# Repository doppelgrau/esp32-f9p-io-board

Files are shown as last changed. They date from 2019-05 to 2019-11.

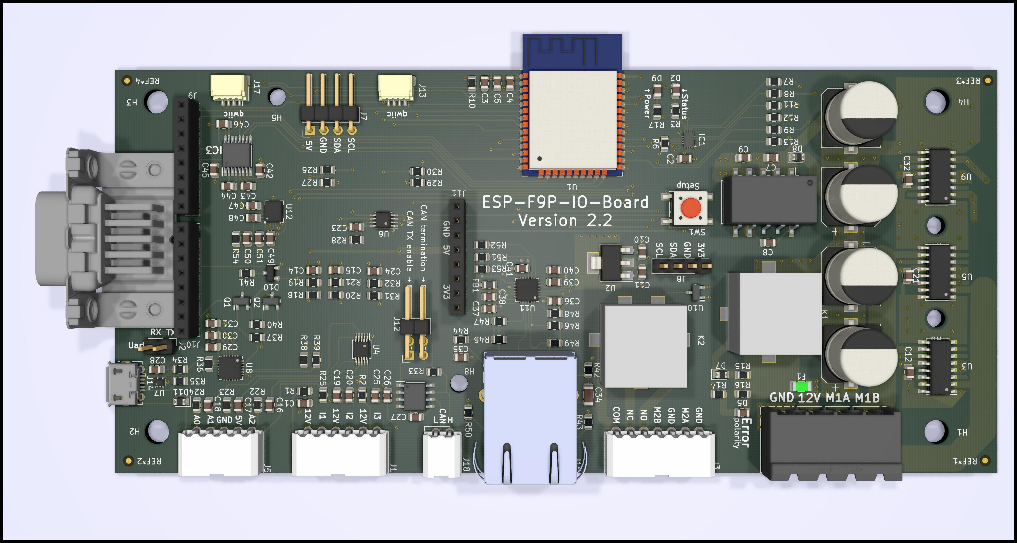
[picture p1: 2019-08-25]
pcb/mainPCB.jpeg

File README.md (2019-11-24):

# ESP32 F9P IO board

This PCB is a versatile IO plattform that provides computing power (ESP32) and IO interfaces to build GPS/RTK applications.

## Hardware Overview

- Power supply: 
    - Input 9V-28V (labeld 12V on the board), external connection on J4. 
    - Protected against wrong polarity (Diode D7 parallel to the relay K1)
    - Reduced inrush current (resistors R15/16 in serie with the starting diode D7 before the relay K1 closes and shortens the path).
    - V78E05-1000 (step down converter) PS1 generates 5V
    - AZ1117-3.3 LDO U2 generates 3V from the 5V supply.
    - 12A (slow) fuse soldered on the board. Recommended to use a 10A external fuse.
- ESP32-WROOM-32 U1 for computing-power, wifi, Bluetooth
- Arduino headers for the simpleRTK2B-F9P (uart 1 of the F9P connected)
- Serial interfaces
    - one uart (IO13/14) on the Arduino headers for the F9P
    - one uart (IO0/2) next to the arduino headers on two pins (J2) for the new simpleRTK2Blight. Since the two pins have a special meaning during boot, pulling TX to GND during startup results in the ESP going into programming mode.
    - one uart (IO15/16) for RS232 on the D-Sub connector J16
    - one uart (IO1/3) on the USB-Uart converter (J14) - Also supports programming with "RTS/DTR"
- I2C (IO32/33)
    - I2C with 3.3V logic level (J8 pin header, J13,17 [qwiic](https://www.sparkfun.com/qwiic) connector)
    - I2C with 5V logic level (J7 pin header)
    - internal used adresses:
        - 0x1C - Magnetometer part of the LSM9DS1 (U12)
        - 0x43 - FXL6408 port extender (IC 1)
        - 0x48 - ADS1115 (U4)
        - 0x6A - Accelerometer part of the LSM9DS1 (U12)
- CAN bus
    - Tranceiver (U2) + ESP32 integrated controler (TX IO5, RX IO35)
    - Termination resistor and sending messages can/must both be enabled with a jumper on J12
    - external connection J18
- Ethernet:
    - internal MAC, connected to LAN8720A on IO17,18,19,21,22,23,25,26,27
        - IO17 Clock
        - IO18 MDIO
        - IO23 MDC
    - PHY-Reset controlled with FXL6408-GPI01
    - ETH-Address of the LAN8720: 0
- IMU: 9 Axis, LSM9DS1 (U12). Magnetometer needs iron correction to be usable.
- Outputs
    - One H-bridge/motordriver with two VNH7070AS (U3/5), (PWM IO4, FXL6408-GPIO6/7 direction). External connected on J4
    - One H-bridge/motordriver with one VNH7070AS (U9), (PWM IO12, FXL6408-GPI04/5 direction), external connected on J3
    - One Relay (K2) controlled on FXL6408-GPI03, external connected on J3
    - One status LED (D2) controlled on FXL6408-GPI02
- Inputs
    - Three 15V tolerant (analog) inputs IO34, SENSOR_VN/36, SENSOR_VP/39, external connected on J1
    - Three 5V tolerant (analog) inputs on the ADS1115, first two cann be used to measure differential. Number four is hardwired to VCC/5V. External connected on J5
    - One Button (e.g. for entering configuration mode), on FXL6408-GPI00
- Connectors:
    - J1 - 6 pin PTSM header. 15V tolerant inputs and 12V for easy cabeling if used as switch
    - J2 - 2 Pin Uart
    - J3 - 7 pin PTSM header. Outputs of second H-bridge, two times ground (for using as two half bridges) and the three pins for the relay (comm, no, nc)
    - J4 - 4 pin CCA header. Power input and output of the first motor driver/h-bridge
    - J5 - 5 pin PTSM header. Three ADS1115 inputs, 5V and GND for easy cabeling (e.g. linear potentiometer)
    - J7 - 4 pin header. I2C 5V logic level + GND and 5V
    - J8 - 4 pin header. I2C 3V3 logic level + GND and 3V3
    - J9, J10, J11 - 8 pin header. Socket for the simpleRTK2B F9P
    - J12 - 2x2 horizontal pin header. Used for jumpers to enable CAN termination and/or CAN TX
    - J13, J17 - qwiic connector. I2C 3V3
    - J14 - micro USB connector. Can power 5V and 3V3 part of the PCB. Electricaly not isolated! Used for programming the ESP32
    - J15 - RJ45 ethernet connector
    - J16 - D-Sub connector (male). RS232
    - J18 - 2 pin PTSM header. CAN bus

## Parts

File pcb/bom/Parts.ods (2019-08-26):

Ref | Qnty | Value | Mouser Partnumber | Mouser Alternative | Digikey | Cmp name | Footprint | Description | Vendor
C1, C3, C4, C2, C8, C12, C19, C21, C27, C26, C28, C30, C29, C32, C35, C39, C41, C36, C38, C45, C44, C46, C43, C42, C51, C49, C48, | 27 | 100n | 603-CC805KRX7R9BB104 |  |  | C | Capacitor_SMD:C_0805_2012Metric | Unpolarized capacitor
C5, C10, C11, C9, C20, C25, C37, | 7 | 22u | 963-LMK212BBJ226MG-T |  |  | C | Capacitor_SMD:C_0805_2012Metric | Unpolarized capacitor
C6, C13, C22, C33, | 4 | 560u | 647-UCM1V561MNL1GS |  |  | CP | Capacitor_SMD:CP_Elec_10x10.5 | Polarized capacitor
C7, C50, | 2 | 10u | GRM21BC8YA106ME11L |  |  | C | Capacitor_SMD:C_0805_2012Metric | Unpolarized capacitor
C14, C15, C17, C18, C16, C23, C24, | 7 | 1n | 710-885012207033 |  |  | C | Capacitor_SMD:C_0805_2012Metric | Unpolarized capacitor
C31, C40, | 2 | 2.2u | 963-LMK212BJ225KG-T |  |  | C | Capacitor_SMD:C_0805_2012Metric | Unpolarized capacitor
C34, | 1 | 1n/2000V | 605-202R18W102KV4E |  |  | C | Capacitor_SMD:C_1206_3216Metric | Unpolarized capacitor
C47, | 1 | 10n | 603-CC805KRX7R9BB103 |  |  | C | Capacitor_SMD:C_0805_2012Metric | Unpolarized capacitor
D2, | 1 | LED/blue | 710-150080BS75000 |  |  | LED | Capacitor_SMD:C_0805_2012Metric | Light emitting diode
D5, | 1 | LED/red | 710-150080VS75000 |  |  | LED | Capacitor_SMD:C_0805_2012Metric | Light emitting diode
D9, | 1 | LED/green | 710-150080RS75000 |  |  | LED | Capacitor_SMD:C_0805_2012Metric | Light emitting diode
D7, D8, D11, | 3 | SD0805S020S1R0 | 581-SD0805S020S1R0 | 750-ACDBS140-HF | 478-7800-1-ND | D | Diode_SMD:D_0805_2012Metric | Diode
D10, | 1 | BAT54C | 863-BAT54CLT1G |  | BAT54CFSCT-ND | BAT54C | Package_TO_SOT_SMD:SOT-23 | dual schottky barrier diode, common cathode
F1, | 1 | 12A/slow | 693-3413.0329.22 |  | 486-1687-1-ND | Fuse | ICs_own:Fuse_1206_3216Metric | Fuse
FB1, | 1 | 600R/2A | 571-1-1624117-7 |  | A102078CT-ND | Ferrite_Bead | Inductor_SMD:L_0805_2012Metric | Ferrite bead
IC1, | 1 | FXL6408UMX | 512-FXL6408UMX |  | FXL6408UMXCT-ND | FXL6408UMX | ICs_own:QFN40P180X260X55-16N | Fully Configurable 8-Bit I2C-Controlled GPIO Expander
IC2, | 1 | ATA6561-GAQW-N | 579-ATA6561-GAQW-N |  | ATA6561-GBQW-NCT-ND | ATA6561-GAQW-N | ICs_own:SOIC127P600X175-8N | MICROCHIP - ATA6561-GAQW-N - CAN TRANSCEIVER, 5MBPS, -40 TO 150DEG C
IC3, | 1 | ICL3221EIVZ | 968-ICL3221EIVZ |  | ICL3221EIVZ-ND | ICL3221EIVZ-ND | ICs_own:SOP65P640X120-16N | Intersil ICL3221EIVZ, Line Transceiver, EIA/TIA-232/ RS-232/ V.24/ V.28, 3.3 V, 5 V, 16-Pin TSSOP
J1, | 1 | PTSM-Header-Horizontal-6 | 651-1814883 |  | 277-9960-1-ND | PTSM-Header-Horizontal-6 | Connector_own:1814883
J3, | 1 | PTSM-Header-Horizontal-7 | 651-1814896 |  | 277-9961-1-ND | PTSM-Header-Horizontal-7 | Connector_own:1814896
J4, | 1 | CCA-Header-Horizontal-4 | 651-1836366 |  | 277-16334-ND | 277-16334-ND | Connector_own:1836366
J5, | 1 | PTSM-Header-Horizontal-5 | 651-1814870 |  | 277-9959-1-ND | PTSM-Header-Horizontal-5 | Connector_own:1814870
J7, | 1 | Conn_01x04_Male | 649-68016-404HLF |  |  | Conn_01x04_Male | Connector_PinHeader_2.54mm:PinHeader_1x04_P2.54mm_Horizontal | Generic connector, single row, 01x04, script generated (kicad-library-utils/schlib/autogen/connector/)
J8, | 1 | Conn_01x04_Male | 855-M20-9770446 |  |  | Conn_01x04_Male | Connector_PinHeader_2.54mm:PinHeader_1x04_P2.54mm_Vertical | Generic connector, single row, 01x04, script generated (kicad-library-utils/schlib/autogen/connector/)
J9, J10, J11, | 3 | Conn_01x08_Female | 855-M20-7820842 |  |  | Conn_01x08_Female | Connector_PinSocket_2.54mm:PinSocket_1x08_P2.54mm_Vertical | Generic connector, single row, 01x08, script generated (kicad-library-utils/schlib/autogen/connector/)
J12, | 1 | Conn_02x02_Odd_Even | 649-68021-404HLF |  |  | Conn_02x02_Odd_Even | Connector_PinHeader_2.54mm:PinHeader_2x02_P2.54mm_Horizontal | Generic connector, double row, 02x02, odd/even pin numbering scheme (row 1 odd numbers, row 2 even numbers), script generated (kicad-library-utils/schlib/autogen/connector/)
J13, J17, | 2 | SM04B-SRSS-TB(LF)(SN) | 474-PRT-14417 |  | 455-1804-1-ND | SM04B-SRSS-TB(LF)(SN) | Connector_own:JST_SH_SM04B-SRSS-TB_1x04-1MP_P1.00mm_Horizontal | JST (JAPAN SOLDERLESS TERMINALS) - SM04B-SRSS-TB(LF)(SN) - CONNECTOR, HEADER, SMT, R/A, 1MM, 4WAY
J14, | 1 | USB_B_Micro | 538-105017-0001 |  | WM1399CT-ND | USB_B_Micro | Connector_own:USB_Micro-B_Molex-105017-0001 | USB Micro Type B connector
J15, | 1 | RJ45_Amphenol_RJMG1BD3B8K1ANR | 523-RJMG1BD3B8K1ANR |  | RJMG1BD3B8K1ANR-ND | RJ45_Amphenol_RJMG1BD3B8K1ANR | Connector_own:RJ45_Amphenol_RJMG1BD3B8K1ANR | 1 Port RJ45 Magjack Connector Through Hole 10/100 Base-T, AutoMDIX
J16, | 1 | DB9_Male_MountingHoles | 649-LD09P33E4GV00LF |  | 609-5186-ND | DB9_Male_MountingHoles | Connector_own:LD09P33E4GV00LF | 9-pin male D-SUB connector, Mounting Hole
J18, | 1 | PTSM-Header-Horizontal-2 | 651-1814841 |  | 277-9956-1-ND | PTSM-Header-Horizontal-2 | Connector_own:1814841
K1, K2, | 2 | CP1SA-12V-Z | 769-CP1SA-12V-Z |  | 255-3417-1-ND | CP1SA-12V-Z | Relay_own:CP1SA12VZ | PANASONIC ELECTRIC WORKS - CP1SA-12V-Z - RELAY, AUTOMOTIVE, SPDT, 14VDC, 20A
PS1, | 1 | V78E05-1000-SMT-TR | 490-V78E05-1000SMTTR |  | 102-5033-1-ND | V78E05-1000-SMT-TR | ICs_own:SOP254P1140X825-10N
Q2, Q1, | 2 | BC817-40,215 | 771-BC817-40-T/R |  | 1727-2919-1-ND | BC817-40,215 | ICs_own:SOT95P230X110-3N | BC817; BC817W; BC337 - 45 V, 500 mA NPN general-purpose transistors
R1, R25, R33, R39, R38, R41, | 6 | 120 | 652-CR0805FX-1200ELF |  |  | R | Resistor_SMD:R_0805_2012Metric | Resistor
R3, R17, | 2 | 620 | 71-CRCW0805620RFKEAC |  |  | R | Resistor_SMD:R_0805_2012Metric | Resistor
R10, R6, R18, R20, R24, R23, R22, R31, R35, | 9 | 47k | 71-CRCW080547K0FKEAC |  |  | R | Resistor_SMD:R_0805_2012Metric | Resistor
R11, R12, R13, R7, R8, R9, R36, R37, R40, | 9 | 1k | 71-CRCW08051K00FKEAC |  |  | R | Resistor_SMD:R_0805_2012Metric | Resistor
R14, R26, R27, R30, R29, R43, R50, R51, R52, R53, | 10 | 2.4k | 603-RC0805FR-072K4L |  |  | R | Resistor_SMD:R_0805_2012Metric | Resistor
R2, R16, R15, R54, | 4 | 24 | 603-RC0805FR-0724RL |  |  | R | Resistor_SMD:R_0805_2012Metric | Resistor
R19, R21, R32, R48, | 4 | 12.1k | 71-CRCW080512K1FKEAC |  |  | R | Resistor_SMD:R_0805_2012Metric | Resistor
R28, | 1 | 220k | 652-CR0805JW-224ELF |  |  | R | Resistor_SMD:R_0805_2012Metric | Resistor
R34, | 1 | 22.1k | 652-CR0805FX-2212ELF |  |  | R | Resistor_SMD:R_0805_2012Metric | Resistor
R42, R44, | 2 | 0 | 603-RC0805JR-070RL |  |  | R | Resistor_SMD:R_0805_2012Metric | Resistor
R45, R46, R47, R49, | 4 | 49.9 | 71-CRCW080549R9FKEAC |  |  | R | Resistor_SMD:R_0805_2012Metric | Resistor
SW1, | 1 | SW_Push | 611-PTS645SM43SMTR92 |  | CKN9112CT-ND | SW_Push | Button_Switch_SMD:SW_SPST_PTS645 | Push button switch, generic, two pins
U1, | 1 | ESP32-WROOM-32 | 356-ESP-WROOM-32 |  | 1904-1023-1-ND | ESP32-WROOM-32 | RF_Module:ESP32-WROOM-32 | RF Module, ESP32-D0WDQ6 SoC, Wi-Fi 802.11b/g/n, Bluetooth, BLE, 32-bit, 2.7-3.6V, SMD
U2, | 1 | AZ1117-3.3 | 621-AZ1117IH-3.3TRG1 |  | AZ1117EH-3.3TRG1DICT-ND | AZ1117-3.3 | Package_TO_SOT_SMD:SOT-223-3_TabPin2 | 1A 20V Fixed LDO Linear Regulator, 3.3V, SOT-89/SOT-223/TO-220/TO-252/TO-263
U3, U5, U9, | 3 | VNH7070AS | 511-VNH7070ASTR |  | 497-17630-1-ND | 497-17630-1-ND | Package_SO:SOIC-16_3.9x9.9mm_P1.27mm | The device is a full bridge motor driver intended for a wide range of automotive applications.
U4, | 1 | ADS1115IDGS | 595-ADS1115IDGSR |  | 296-38849-1-ND | ADS1115IDGS | Package_SO:MSOP-10_3x3mm_P0.5mm | Ultra-Small, Low-Power, I2C-Compatible, 860-SPS, 16-Bit ADCs With Internal Reference, Oscillator, and Programmable Comparator, VSSOP-10
U6, | 1 | PCA9306DCTR | 595-PCA9306DCTR |  | 296-18509-1-ND | PCA9306 | Package_SO:SSOP-8_2.95x2.8mm_P0.65mm | Dual bidirectional I2C Bus and SMBus voltage level translator
U7, | 1 | TPD3E001DRLR | 595-TPD3E001DRLR |  | 296-21885-1-ND | TPD3E001DRLR | Package_TO_SOT_SMD:SOT-553 | TPD3E001 Low-Capacitance 3-Channel ESD-Protection for High-Speed Data Interfaces
U8, | 1 | CP2102N-A01-GQFN24 | 634-CP02NA01GQFN24R |  | 336-5887-ND | 336-5887-ND | Package_DFN_QFN:QFN-24-1EP_4x4mm_P0.5mm_EP2.6x2.6mm | USB to UART master bridge
U10, | 1 | NUD3124LT1G | 863-NUD3124LT1G |  | NUD3124LT1GOSCT-ND | NUD3124LT1G | ICs_own:SOT95P237X100-3N | ON Semiconductor NUD3124LT1G, MOSFET Power Driver, 150mA, 3-Pin SOT-23
U11, | 1 | LAN8720A | 579-LAN8720ACPTRABC |  | LAN8720A-CP-TR-ABCCT-ND | LAN8720A | Package_DFN_QFN:QFN-24-1EP_4x4mm_P0.5mm_EP2.6x2.6mm | LAN8720 Ethernet PHY with RMII interface
U12, | 1 | LSM9DS1 | 511-LSM9DS1TR |  | 497-14946-1-ND | LSM9DS1 | Package_LGA:LGA-24L_3x3.5mm_P0.43mm | I2C SPI 9 axis IMU accelerometer gyroscope magnetometer

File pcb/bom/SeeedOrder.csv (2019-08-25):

Designator | MPN/Seeed SKU | Qty
C1, C3, C4, C2, C8, C12, C19, C21, C27, C26, C28, C30, C29, C32, C39, C41, C36, C38, C45, C44, C46, C43, C42, C51, C49, C48,C35 | 302010165 | 27
C5, C10, C11, C9, C20, C25, C37 | C2012X5R1E226MT000E | 7
C7, C50 | 302010178 | 2
C14, C15, C17, C18, C16, C23, C24 | CL21C102JBCNNNC | 7
C31, C40 | 302010148 | 2
C34 | 202R18W102KV4E | 1
C47 | 302010175 | 1
D2 | 304090039 | 1
D5 | 304090046 | 1
D9 | 304090057 | 1
D7, D8, D11 | SD0805S020S1R0 | 3
D10 | BAT54CLT1G | 1
F1 | 3413.0329.22 | 1
FB1 | 1-1624117-7 | 1
IC1 | FXL6408UMX | 1
IC2 | ATA6561-GAQW-N | 1
IC3 | ICL3221EIVZ | 1
J14 | 105017-0001 | 1
PS1 | V78E05-1000-SMT-TR | 1
Q2, Q1 | BC817-40,215 | 2
R1, R25, R33, R39, R38, R41 | 301010351 | 6
R3, R17 | CRCW0805620RFKEAC | 2
R10, R6, R18, R20, R24, R23, R22, R31, R35 | CRCW080547K0FKEAC | 9
R11, R12, R13, R7, R8, R9, R36, R37, R40 | 301010311 | 9
R14, R26, R27, R30, R29, R43, R50, R51, R52, R53 | 301012194 | 10
R2, R16, R15, R54 | RC0805FR-0724RL | 4
R19, R21, R32, R48 | 0805W8F1212T5E | 4
R28 | RC0805FR-07220KL | 1
R34 | 0805W8F2212T5E | 1
R42, R44 | 301011479 | 2
R45, R46, R47, R49 | 0805W8F499JT5E | 4
SW1 | PTS645SM43SMTR92LFS | 1
U1 | ESP32-WROOM-32 | 1
U2 | AZ1117IH-3.3TRG1 | 1
U3, U5, U9 | VNH7070ASTR | 3
U4 | ADS1115IDGSR | 1
U6 | PCA9306DCTR | 1
U7 | TPD3E001DRLR | 1
U8 | CP2102N-A01-GQFN24R | 1
U10 | NUD3124LT1G | 1
U11 | LAN8720A-CP-TR-ABC | 1
U12 | LSM9DS1TR | 1

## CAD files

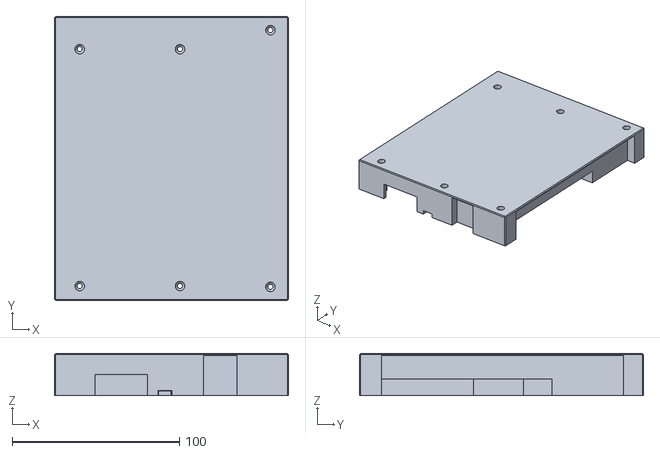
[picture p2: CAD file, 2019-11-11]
cases/Basic-1xF9P/Case_MainCover.stl
140.0 x 170.0 x 25.2

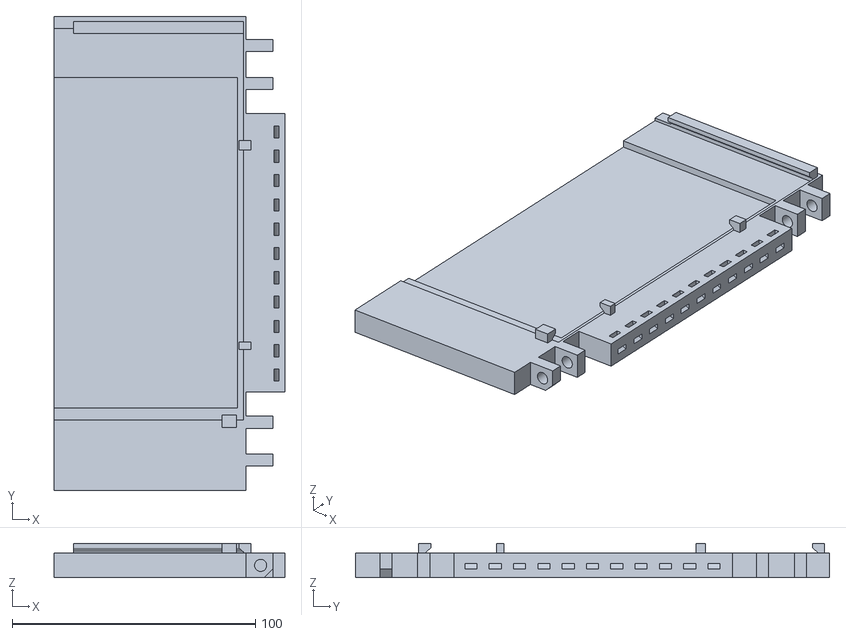
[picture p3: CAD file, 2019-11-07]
cases/Test-Setup/top.stl
95.0 x 195.0 x 14.0

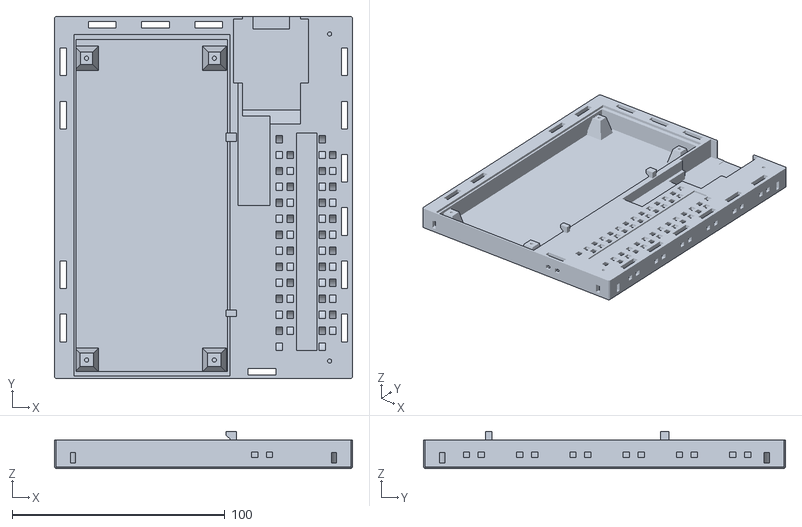
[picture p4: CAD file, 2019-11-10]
cases/Basic-1xF9P/Case_Baseplate.stl
140.0 x 170.0 x 17.5

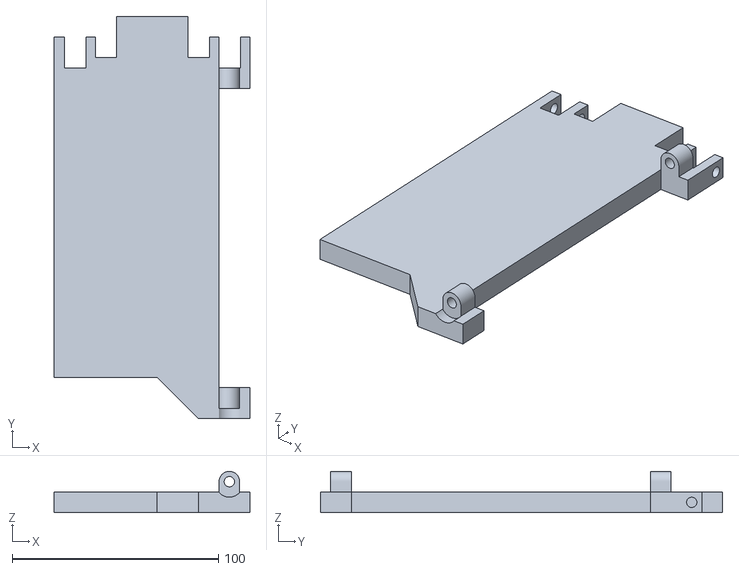
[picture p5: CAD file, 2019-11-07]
cases/Test-Setup/Middle.stl
95.0 x 195.0 x 20.0

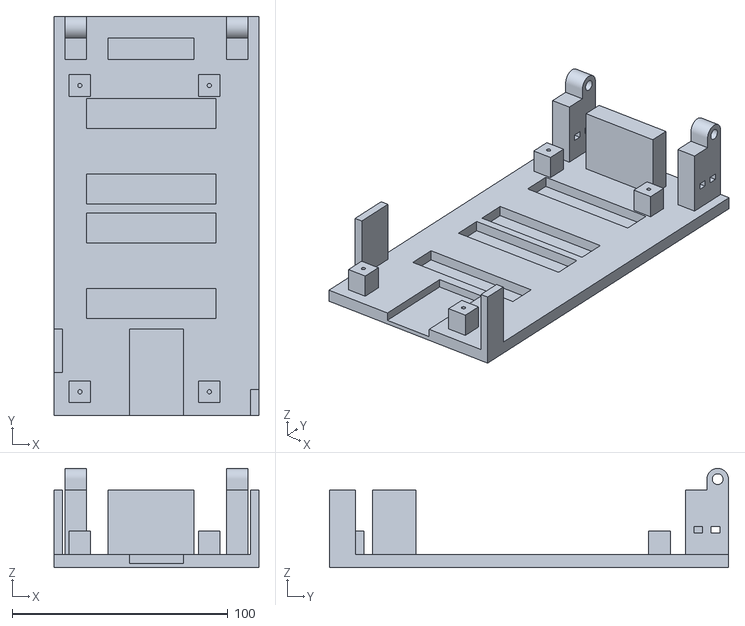
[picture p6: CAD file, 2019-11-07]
cases/Test-Setup/Base.stl
95.0 x 185.0 x 46.0

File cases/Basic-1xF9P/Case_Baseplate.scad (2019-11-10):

// to allow easier adjustments pcb is laying on the plane created by x and y-axis.  H3, H4 on y. H3, H2 on x
// 1.5mm of the pcb embedded in this part
error = 0.15; // how much increase for error during print
$fn=100;

// helper modules
module pcbHolder(center=[0,0,0],height=10.8,baseDia=16,topDia=8, screw=2) {
    translate(center){
        difference() {
            rotate([0,0,45]) cylinder(height,baseDia/2,topDia/2,$fn=4);
            translate([0,0,1]) cylinder(h=height+1, r=screw/2);
        };
    };
};

module wireStrapHolder(center=[0,0,0], rotation=[0,90,0], inner=2.0, outer=5.5, width=2.75+2*error) {
    translate(center){
        rotate(rotation){
            difference(){
                translate([0,0,-width/2]) cylinder(h=width, r=outer, center = true);
                translate([0,0,-width/2]) cylinder(h=width, r=inner, center = true);
                translate([0,0,outer]) cube(2*outer, center=true);

            };
        };
    };
};

module edgeHolder(center=[0,0,0],angle=0) {
   translate(center){
       rotate([0,0,angle]) {
        cube([3,13,14], center=true);
        translate([0,2,-1.5]) cube([30,3,2.5]);
        translate([0,-5,-1.5]) cube([30,3,2.5]);
       };
    };
};

module switchSpace() {
    translate([0,-45,0]) cube([27+2*error,45,12]); // long inner part
    translate([5,-7,-0.3]) cube([17+2*error,7,1]); // dent for the small triangles at the side
    translate([-4,-32.4,0]) cube([35,30,12]); // wider space inside
    translate([0,-65,35]) rotate([-60,0,0]) cube([27+2*error,40,20]); // angle at the end
    translate([-2,-90,5.5]) cube([15,60,12]); // a bit space for cable management (under J3
}

module pcbClamp(center=[0,0,0], rotation=[0,0,0], l=10) {
    translate(center){
        rotate(rotation){
            difference(){
                cube([l,5,4], center = true);
                translate([0,1.5,-1.8]) cube([l,2,0.6], center = true); // pcb
                translate([0,2.67,-1]) rotate([40,0,0]) cube([l,4,2], center=true);
            };
        };
    };
};

// main design
difference(){
    // base form
    translate([-9.2,-1.2,-12]){
      cube([140,170,13.5]);
    };
    // pcb itselfwireStrapHolder
    cube([73+2*error,160.1+2*error,1.6]);
    //space below the pcb
    translate([1,2,-10.8]){
      cube([71,156,11]);
    };
    // space for the switch
    translate([79,170,-10.5]) switchSpace();

    // a bit lower for isolation foam (1mm)
    translate([104.5 ,12, 0.5]) cube([9.5,102,3.01]);
    // holder for wire straps (cables)
    for (a =[25:15:110]) wireStrapHolder([103, a, 1.5]);
    for (a =[17.5:15:110]) wireStrapHolder([98, a, 1.5]);
    // corner rows
    for (a =[25:15:110]) wireStrapHolder([123, a, 1.5]);
    for (a =[17.5:15:110]) wireStrapHolder([118, a, 1.5]);

    // corner (whole box)
     wireStrapHolder(center=[140-9.2,-1.2,-4.35], rotation=[0,0,0], inner=7.5, outer=10, width=5);
     wireStrapHolder(center=[140-9.2,170-1.2,-4.35], rotation=[0,0,0], inner=7.5, outer=10, width=5);
     wireStrapHolder(center=[-9.2,-1.2,-4.35], rotation=[0,0,0], inner=7.5, outer=10, width=5);
     wireStrapHolder(center=[-9.2,170-1.2,-4.35], rotation=[0,0,0], inner=7.5, outer=10, width=5);
    // edgeHolder 
    for (a =[22.5:25:155]) edgeHolder([127, a, -5.25]);
    for (a =[22.5 - 9.2:25:70]) edgeHolder([a, 165, -5.25], 90);
    for (a =[22.5 - 9.2+75:25:110]) edgeHolder([a, 2, -5.25], 270);
    // keep the antenna out
    for (a =[22.5:25:65]) edgeHolder([-5, a, -5.25],180);
    for (a =[122.5:25:155]) edgeHolder([-5, a, -5.25],180);
    // holes for the screws for the lid 
    translate([120,170-2*1.2-7, -3]) cylinder(h=10,r=2/2,center=true);
    translate([120,7, -3]) cylinder(h=10,r=2/2,center=true);    
    
    // outside edges 45° about 0.5mm
    translate([-9.2,-1.2,10]) rotate([0,0,45]) cube([1,1,50], center=true);
    translate([-9.2,-1.2+170,10]) rotate([0,0,45]) cube([1,1,50], center=true);
    translate([-9.2+140,-1.2,10]) rotate([0,0,45]) cube([1,1,50], center=true);
    translate([-9.2+140,-1.2+170,10]) rotate([0,0,45]) cube([1,1,50], center=true);
    translate([65,-1.2,-12]) rotate([-45,0,0]) cube([150,1,1], center=true);
    translate([65,-1.2+170,-12]) rotate([-45,0,0]) cube([150,1,1], center=true);
    translate([-9.2,85,-12]) rotate([0,45,0]) cube([1,180,1], center=true);
    translate([-9.2+140,85,-12]) rotate([0,45,0]) cube([1,180,1], center=true);
};
// pcbHolder, tanslate all on the bottom layer
translate([0,0,-10.8]) {
    pcbHolder(center=[5.9, 7.5,0], topDia=9);
    pcbHolder(center=[65.9,7.5,0], topDia=9);
    pcbHolder(center=[5.9,149.2,0]);
    pcbHolder(center=[65.9,149.2,0]);
};

// help during mount
pcbClamp(center=[73.8,29.5,3.5], rotation=[0,0,90], l=3);
pcbClamp(center=[73.8,112,3.5], rotation=[0,0,90], l=4);

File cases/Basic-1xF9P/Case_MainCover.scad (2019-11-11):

// to allow easier adjustments the top of the pcb is laying on the plane created by x and y-axis.  H3, H4 on y. H3, H2 on x
// 0.1mm of pcb not in the lower part
// printed turned by 180° (but so the coordinated match with the lower part)
error = 0.15; // how much increase for error during print
$fn=100;

// helper modules
module screwHole(center=[0,0,0],height=24.85,inner=5.7,wall=1.6, hole=3.0, slope=1.8) {
    translate(center) {
        difference() {
            translate([0,0,height/2]) cylinder(h=height, r=inner/2+2*wall/2+0.01, center = true);
            translate([0,0,height/2]) cylinder(h=height, r=hole/2, center = true);
            translate([0,0,(height - wall - slope)/2+wall+slope]) cylinder(h=height - wall - slope, r=inner/2, center = true);
            translate([0,0,slope/2 + wall]) cylinder(h=slope, r1=hole/2, r2=inner/2, center = true);
        };
    };
};

// main design
difference(){
    // base form
    translate([-9.2,-1.2,0]) cube([140,170,25.25]);
    // 0.2mm for the pcb
    translate([0,0,-0.1]) cube([73+4*error,160.1+2*error,0.3]);
    // space above pcb (1mm/1.5 of the small sides solid)
    translate([0,1.5,-0.1]) cube([73+2*error,157.6+2*error,24.1]);
    // space for esp32 antenna
    translate([-7.9,67,-0.1]) cube([8,30,24.1]);
    // space above the side holder
    translate([-10,11,-0.1]) cube([8,54.5,24.1]);
    translate([-10,98.5,-0.1]) cube([8,62,24.1]);
    translate([2,163,-0.1]) cube([70,8,24.1]);
    translate([80,-3,-0.1]) cube([20,8,24.1]);
    translate([140-9.2-7,12,-0.1]) cube([8,170-1.2-2*12,24.1]);
    // space between the dust isolation
    translate([70 ,12, -0.1]) cube([80,102,10.1]);
    // holder for the dust isolation
    translate([104.5 ,12, 0]) cube([9.5,102,11]);
    // space behind the isolation to the pcb
    translate([70 ,12, -0.1]) cube([30,130,24.1]);
    // holes for screws
    translate([120,170-2*1.2-7, -3]) cylinder(h=100, r=3, center = true);
    translate([120,7, -3]) cylinder(h=100, r=3, center = true);
    translate([5.9, 7.5,0]) cylinder(h=100, r=3, center = true);
    translate([65.9,7.5,0]) cylinder(h=100, r=3, center = true);
    translate([5.9,149,0]) cylinder(h=100, r=3, center = true);
    translate([65.9,149,0]) cylinder(h=100, r=3, center = true);
    // openning rs232
    translate([15.2-error,-1.25,0]) cube([31.2+2*error,4,12.5+0.1+error]);
    //openning usb (front a bit wider than the rest
    translate([53.2-error,-1.25,0]) cube([7.6+2*error,4,2.6+0.1+error]); // main
    translate([53.0-error,-1.25,0]) cube([8+2*error,1.6,2.85+0.1+error]); // main

    // space for the switch
    translate([84,163,-0.4]) cube([17+2*error,7,1]);
    
    // small cutout for the plug and it's holder
    translate([72, 8.5,-0.01]) cube([8.5,4,8]);
    
    // thinner top over the LEDs (e.g. for two color print)
    translate([25,25,23.75]) cube([15,30,1]);
    translate([0,93,23.75]) cube([12,15,1]);
    translate([60,108,23.75]) cube([10,10,1]);
    
    // outside edges 45° about 0.5mm
    translate([-9.2,-1.2,10]) rotate([0,0,45]) cube([1,1,50], center=true);
    translate([-9.2,-1.2+170,10]) rotate([0,0,45]) cube([1,1,50], center=true);
    translate([-9.2+140,-1.2,10]) rotate([0,0,45]) cube([1,1,50], center=true);
    translate([-9.2+140,-1.2+170,10]) rotate([0,0,45]) cube([1,1,50], center=true);
    translate([65,-1.2,25.25]) rotate([-45,0,0]) cube([150,1,1], center=true);
    translate([65,-1.2+170,25.25]) rotate([-45,0,0]) cube([150,1,1], center=true);
    translate([-9.2,85,25.25]) rotate([0,45,0]) cube([1,180,1], center=true);
    translate([-9.2+140,85,25.25]) rotate([0,45,0]) cube([1,180,1], center=true);
};
screwHole(center=[120,170-2*1.2-7, 0.15], height=25.1);
screwHole(center=[120,7, 0.15], height=25.1);
screwHole(center=[5.9, 7.5,0.3], wall=1.2);
screwHole(center=[65.9,7.5,0.3], wall=1.2);
screwHole(center=[5.9,149.2,0.3], wall=2.4);
screwHole(center=[65.9,149.2,0.3], wall=2.4);
// a bit more support (thin walls)
translate([0, 6.5,0.3]) cube([3,2,24]);
translate([69.4, 6.5,0.3]) cube([4.5,2,24]);
translate([4.9, 1,0.3]) cube([2,3,24]);
translate([64.9, 1,0.3]) cube([2,3,24]);
translate([0, 148.2,0.3]) cube([3,2,24]);
translate([69.9, 148.2,0.3]) cube([4,2,24]);
// small support for the thin top
translate([-9, 80, 20]) cube([120,2.4,5]);

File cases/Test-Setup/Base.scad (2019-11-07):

$fn=60;

// methoden
module holder(edge=[0,0,0]) {
    translate(edge){
        difference(){
            union() {
                cube([10,20,30]);
                translate([0,10,0]) cube([10,10,35]);
                translate([0,15,35]) rotate([0,90,0]) cylinder(h=10, d=10);
            };
            translate([0,15,35]) rotate([0,90,0]) cylinder(h=10, d=5);
            translate([0,4,10]) cube([10,4,3]); 
            translate([0,12,10]) cube([10,4,3]); 
        };
    };
};

module pcbHolder(center=[0,0,0],h=12,d=10, screw=2) {
    translate(center){
        difference() {
            union() {
                cube([d,d,h], center=true);
            };
            translate([0,0,1]) cylinder(h=h+1, r=screw/2);
        };
    };
};


// main
translate([0,0,-6]) difference() {
    cube([95,185,6]);
    // for clamp
    translate([35,0,2]) cube([25,40,5]);
    // for resistors
    translate([15,133,1]) cube([60,14,5]);
    translate([15,098,1]) cube([60,14,5]);
    translate([15,080,1]) cube([60,14,5]);
    translate([15,045,1]) cube([60,14,5]);
}
// stopper
translate([25,165,0]) cube([40,10,30]);
translate([0,20,0]) cube([4,20,30]);
translate([91,0,0]) cube([4,12,30]);

// holder
holder(edge=[5,165,0]);
holder(edge=[80,165,0]);
pcbHolder([12,153,5]);
pcbHolder([72,153,5]);
pcbHolder([12,11,5]);
pcbHolder([72,11,5]);

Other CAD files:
cases/Test-Setup/Middle.scad
cases/Test-Setup/top.scad

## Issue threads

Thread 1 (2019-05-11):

Physical: Mounting hole for the F9P

doppelgrau, 2019-05-11:
The front mounting hole to secure the F9P does not fit, movement required

Closed 2019-05-22.

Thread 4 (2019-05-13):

Add some fiducials (>= 3)

doppelgrau, 2019-05-13:
Add some fidducials, so a pick & place machine might be used

doppelgrau, 2019-05-22:
Last one, since changes to eeschema will delete fiducials

doppelgrau, 2019-05-30:
Reopen, had made changes to the schematic => lost
Include updating gerber files.

Closed 2019-06-03.

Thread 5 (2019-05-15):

Check if the xbee-uart is free

doppelgrau, 2019-05-15:
If the xbee-uart is currently connected to the esp32 change to uart2

doppelgrau, 2019-05-22:
Is free, XBEE uses uart2, noch changes necessary

https://www.ardusimple.com/simplertk2b-hookup-guide/
"TX2: XBee UART TX (this pin is also connected to ZED-F9P UART2 RX).
RX2: XBee UART RX (this pin is also connected to ZED-F9P UART2 TX)."

Closed 2019-05-22.

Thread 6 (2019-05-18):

physical location of the LSM9DS1

doppelgrau, 2019-05-18:
Currently placed near the RS232 connector. but connectors and cables introduce metal in the area that can disturb the magnetic field after calibration.
Maybe better placed under the F9P, magnetic error should be more constant there => after calibration not a huge problem

Closed 2019-05-20.

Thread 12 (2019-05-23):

Better software examples

doppelgrau, 2019-05-23:
Provide better examples (maybe libraries?) for:

- IMU iron correction
- IMU gyro correction
 - using the port expander
 - using the VNH7070

doppelgrau, 2019-08-05:
Basic examples exist in the HW-Test.
Nice libraries would be a good next step.

Closed 2019-08-29.

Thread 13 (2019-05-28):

add an other uart for simpleRTK2Blite

doppelgrau, 2019-05-28:
To use two ardusimple F9P (simpleRTK2B and simpleRTK2Blite) for RTK + heading with NTRIP a second UART is needed with an interface so it can be connected to the top module.

- If you use an LR kit with corrections coming over XBee, you only need to connect to 1 UART. This UART will give RTK position + heading, but only in UBX protocol
- If you use NTRIP server, you will need 2 connections, one to send corrections to simpleRTK2Blite, and another one to read RTK position+heading in UBX protocol.

doppelgrau, 2019-05-28:
Making the RS232 or the USB-Uart "switchable" would be the simplest solution, downsides:
 - RS232 can be a nice feature for external controlers needing GPS
 - USB should be normally not used, but "nightmare" user fortgets to switch back and updates won't work

So I guess add a second or larger port expander (IN A/B for the first motorcontroler on port expander => two ports for UART)

doppelgrau, 2019-05-30:
Fixed in commit ccc37e0faeaf5038c0ea7c2db17b82ef1ffa8335

Closed 2019-05-30.

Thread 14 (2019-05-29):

free GND and Power under IMU

doppelgrau, 2019-05-29:
Look again into the datasheet, I think a bit clearance could help

doppelgrau, 2019-05-30:
Wrong memories - no need to change

Closed 2019-05-30.

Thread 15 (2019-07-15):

Can I do everything with one ESP32?

mnltake, 2019-07-15:
Hello doppelgrau.
It is a wonderful work!
I want to use this board for NTRIP Client to F9P, and AutoSteer to AgOpenGPS .
Do you think it is possible in ONE esp32?

doppelgrau, 2019-07-15:
Yes, that should be no problem.
See https://github.com/eringerli/esp32-aog
I plan to port it to the pcb (support ethernet, the port expander, VNH7070, LSM9DS1, ...), but I guess combining the arduino scatches from @Coffeetrac would work, too.

Closed 2019-07-15.

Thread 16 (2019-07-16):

C35 Capacitance Value

mnltake, 2019-07-16:
Thank you for answering my question!
I noticed a small point.

In the circuit diagram "C35" is "100nF/16V"
But in "Parts.ods" C35's Mouser Partnumber is "603-CC805KRX7R9BB103"
it's 10nF.

I think Row"C35,C47,D2,D5,D9"   Colum"Mouser Partnumber-" is wrong.

doppelgrau, 2019-07-16:
Thanks for spotting, yes, all one row off.
Copy & Paste error after last update the part list.
Fixed in 74037ad82de8f45cc274536a5f85ebcb8743d273

Closed 2019-07-16.

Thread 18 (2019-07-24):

Disable power-save mode for RS232

doppelgrau, 2019-07-24:
The uart <-> RS232 converter supports a power-safe mode that might cause trouble.
Pull the FORCEON-pin to high instead of gnd

Closed 2019-08-06.

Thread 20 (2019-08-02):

Evaluate the connectors

doppelgrau, 2019-08-02:
- More robust for USB?
- Keep the PTSM? If so Change Variant? SMD/THT

doppelgrau, 2019-08-30:
Maybe fixed connector?
Evaluate if PTSM fixed/plugable has same footprint so it can be easily exchanged

doppelgrau, 2019-10-14:
A first look: PTSM fixed needs additional holes, but footprint allows witching between plugable or fixed.

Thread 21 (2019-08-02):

Evaluate if a three Port switch is an option

doppelgrau, 2019-08-02:
Two external Ethernet-connections would make daisy-chainning easier

doppelgrau, 2019-11-24:
No software support for switch with RMI-Interface.
Implementing driver a bit "out of scope".

Closed 2019-11-24.

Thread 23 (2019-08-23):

Change xbee-Uart Pins

doppelgrau, 2019-08-23:
Change the Xbee uart PINs with the pwm pins so there won't be any problems if pulled to gnd during startup
(Test before it not pulled down from the VNH and if PWM s okay)

doppelgrau, 2019-08-23:
Won't change.
The IO Pin in that can be used (IO12) has also a special function (voltage of eprom, and a brownout could create hard to debug problems and the TX-pin of the uart should not be pulled to GND.
https://github.com/espressif/esptool/wiki/ESP32-Boot-Mode-Selection

Closed 2019-08-23.

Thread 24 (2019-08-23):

Reduce BOM

doppelgrau, 2019-08-23:
Tests with the oscilloscope show that the inductor in front of the ADS1115 is not much more effective than the RC in front of the LSM9DS1. So to make the BOM shorter changed the inductor to a resistor.

doppelgrau, 2019-08-23:
Done in #c6b8c1d0c264cd49887dd5aff063c8e762b4d9fb

Closed 2019-08-23.

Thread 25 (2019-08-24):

Update BOM, Gerber, ...

doppelgrau, 2019-08-24:
After everything is done, update gerber, bom, ibom, seedstudio files

doppelgrau, 2019-08-25:
Fixed in commit 4a7255df48a5e4a7bd2116502d612ee4538ea036

Closed 2019-08-25.

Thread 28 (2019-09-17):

Rotate PCB Labels

flywire, 2019-09-17:
The following labels are inverted relative to others:
- ESP-F9P-IO-Board
- Version 2.2
- GND / 12V / M1A / M1B
- Uart / RX / TX

doppelgrau, 2019-09-17:
Done on purpose.
Assumes mounting with the antenna on top might be likely => easier to read

flywire, 2019-09-17:
A linked built photo would demonstrate.

doppelgrau, 2019-09-17:
Currently work in progress :)

doppelgrau, 2019-10-14:
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
Foto from the previous version before rotating the writing. looks wrong when mounted with the cables pointing down (less dust enters case)

flywire, 2019-10-14:
Clearly demonstrated. An easy rotate all labels command would have been nice.

Closed 2019-10-14.

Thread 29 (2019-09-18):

PIN for programming mode

mnltake, 2019-09-18:
README.md
> one uart (IO0/2) next to the arduino headers on two pins (J2) for the new simpleRTK2Blight. Since the two pins have a special meaning during boot, pulling RX to GND during startup results in the ESP going into programming mode.

pulling TX to GND   ,I think

Closed 2019-09-22.

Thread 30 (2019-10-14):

Basic-1xF9P: Screws

doppelgrau, 2019-10-14:
Some Redesign do allow larger screws, the M2 work but not enough reserves to be comfortable.

Closed 2019-11-07.

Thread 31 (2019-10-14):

Basic-1xF9P: Space for cable management / switch position

doppelgrau, 2019-10-14:
current position of the switch leaves not enough space for good cable management around the power connector.
So improve free space (top/bottom, wider?) or move power switch

doppelgrau, 2019-11-07:
a bit more space under J3 for cables as fast solution

Closed 2019-11-07.

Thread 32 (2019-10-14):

Basic-1xF9P: holder during installation

doppelgrau, 2019-10-14:
Evaluate if there could not be some sort of support on two or three sides, so the pcb is a bit secured during installation.

doppelgrau, 2019-11-07:
without larger changes only on the connector side enough space

Closed 2019-11-07.

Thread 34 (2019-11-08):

Case: Basic-1xF9P - Thinner top side

doppelgrau, 2019-11-08:
Evaluate if the parts over the LEDs can be made/printed thinner.
If printed with transparent filament it should be more clear and with two color prints it would look nicer.

doppelgrau, 2019-11-10:
done in fe297d32d7b45da904aebc6dc0ea3027ba5aed70

Closed 2019-11-10.

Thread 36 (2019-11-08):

Case: Basic-1xF9P - Slightly rounded outer corners

doppelgrau, 2019-11-08:
make the edges a bit less sharp
Round with a small diameter or a 45° cutoff (0.5mm-1mm?)

doppelgrau, 2019-11-10:
done in #fe297d32d7b45da904aebc6dc0ea3027ba5aed70

Closed 2019-11-10.

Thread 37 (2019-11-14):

Closer look at CAN-interface

doppelgrau, 2019-11-14:
- Improve Termination 2x60 Ohms to Capacitor (one end GND) instead of 120Ohm. Reduces Common Mode Problems
- Check ESD, improve with something like a PESD2CAN

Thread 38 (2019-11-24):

Check IO protection

doppelgrau, 2019-11-24:
Related a bit to #37, check if protection against to high/reverse voltage should be improved

doppelgrau, 2020-02-01:
Answer is yes.
One board already has an ads1115 that always reports the value 0.
Guess all inputs should at least tolerate 15V (12V + errors) for longer times, double as peak

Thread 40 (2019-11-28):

Some visual aid to help with IMU orientation

doppelgrau, 2019-11-28:
Idea: plane with axes, in software rotate pitch/yaw/roll until plane fly in direction of travel

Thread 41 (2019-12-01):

stable reference voltage for steering sensor and analog part of ads1115

doppelgrau, 2019-12-01:

doppelgrau, 2019-12-05:
Evaluate how large the difference is measuring differential to VCC (Input 5 on VCC), might be cheaper solution

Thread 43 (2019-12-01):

divide power supply

doppelgrau, 2019-12-01:
Divide the power supply of the PCB from the Power suppl to the motor driver.
So the motordriver can be easily driven with an other voltage (e.g. 24V)

doppelgrau, 2020-02-01:
After some thinking, not worth the effort.

Closed 2020-02-01.

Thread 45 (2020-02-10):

Fuse for the motors lower and replaceable

doppelgrau, 2020-02-10:

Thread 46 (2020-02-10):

Check optional parts

doppelgrau, 2020-02-10:
Check if there is an option to put different IMUs on the board and only populate the requested (MMA, LSM9DS1 ...)

doppelgrau, 2020-06-03:
IMU: no IMU, max Accelerometer

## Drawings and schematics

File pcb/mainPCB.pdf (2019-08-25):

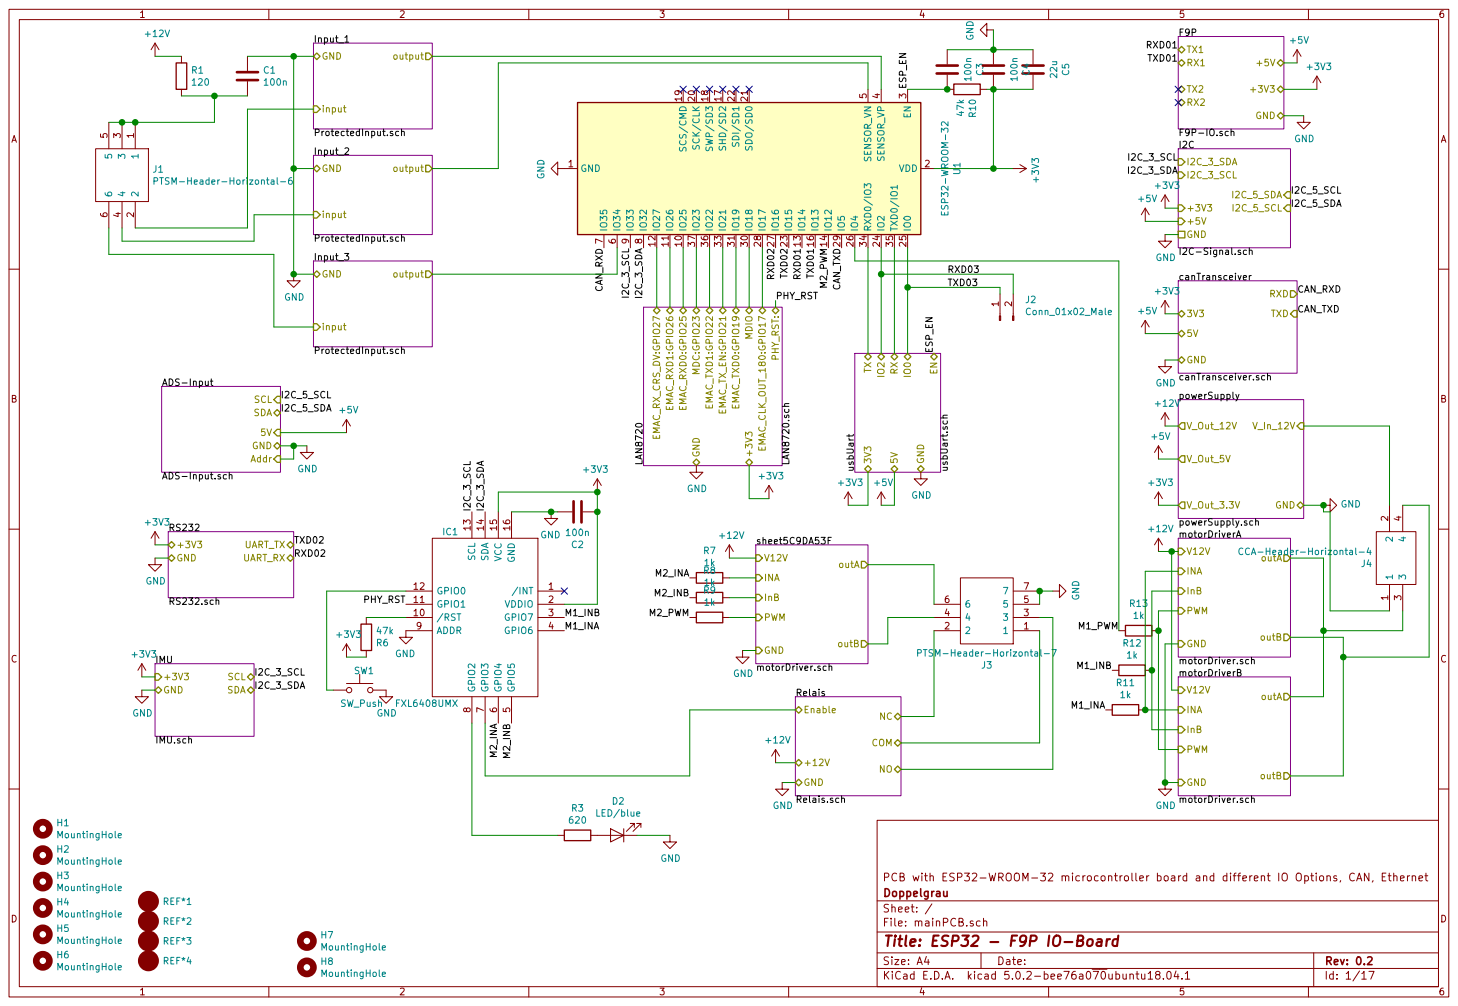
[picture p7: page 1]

J2Conn_01x02_Male M2_INA M2_INB REF*4 REF*3 REF*2 REF*1
IC1 FXL6408UMX I2C_3_SCL I2C_3_SDA GND

PCB with ESP32-WROOM-32 microcontroller board and different IO Options, CAN, Ethernet
File: mainPCB.sch Sheet: / Doppelgrau

Id: 1/17 Title: ESP32 - F9P IO-Board

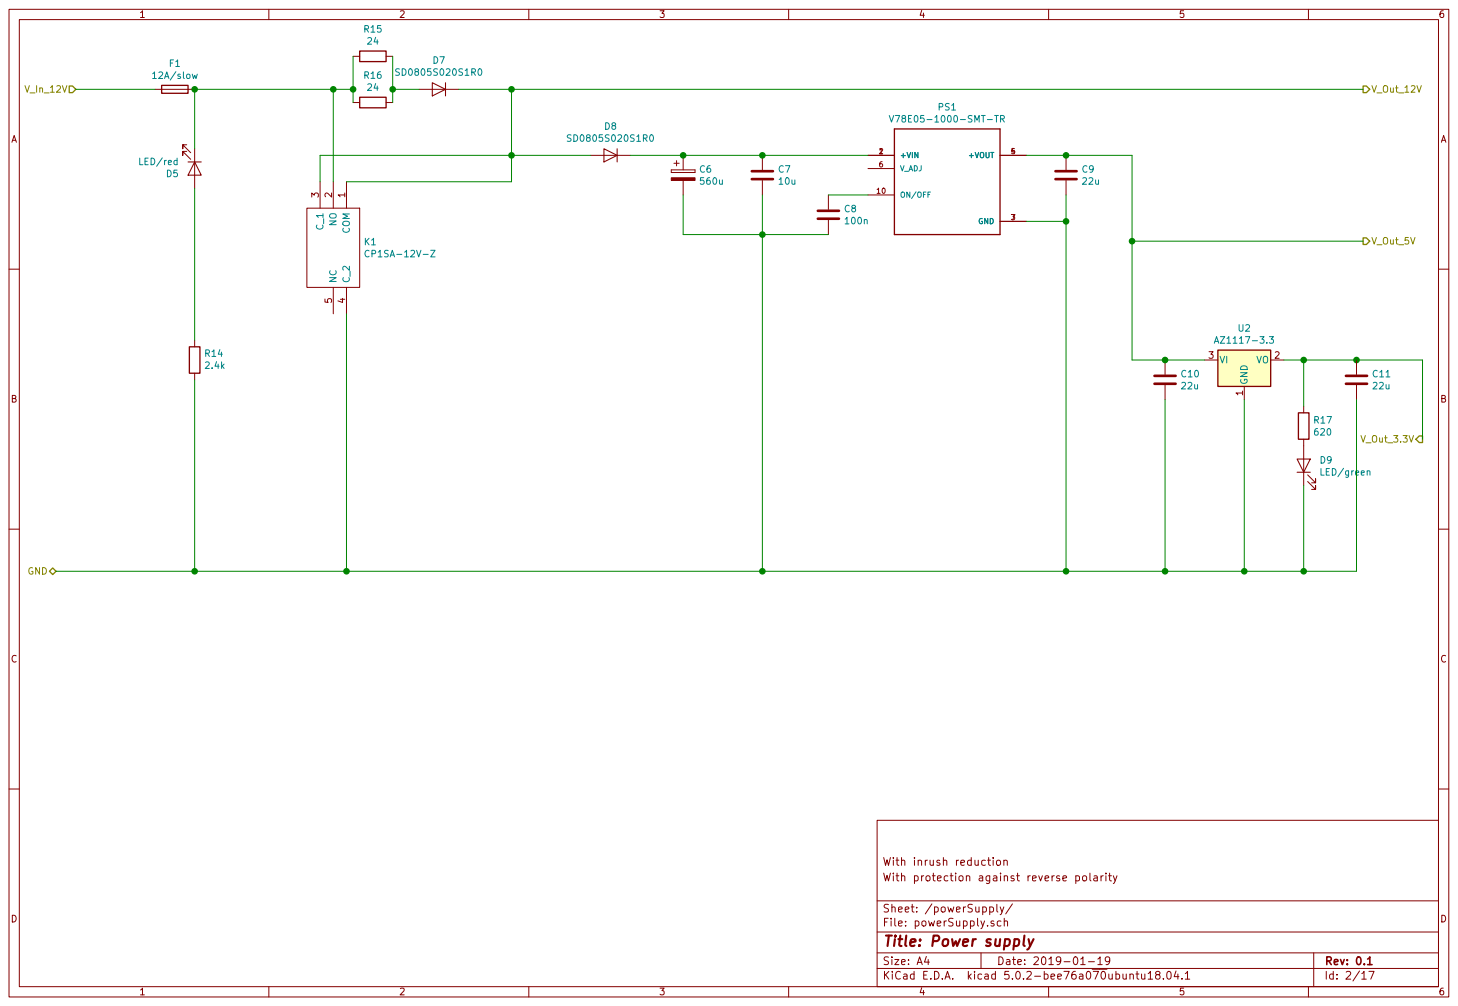
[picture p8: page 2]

With protection against reverse polarity With inrush reduction

Sheet: /powerSupply/
File: powerSupply.sch
Id: 2/17 Title: Power supply

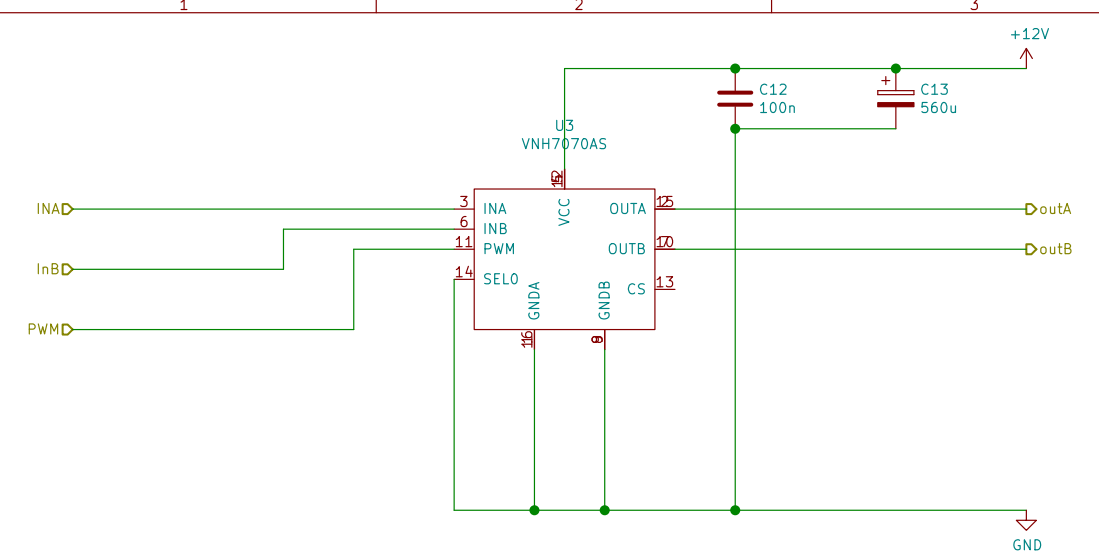
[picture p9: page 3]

Id: 3/17 Title: H-Bridge Motor Driver File: motorDriver.sch Sheet: /motorDriverA/ Based on STM VNH7070ASTR

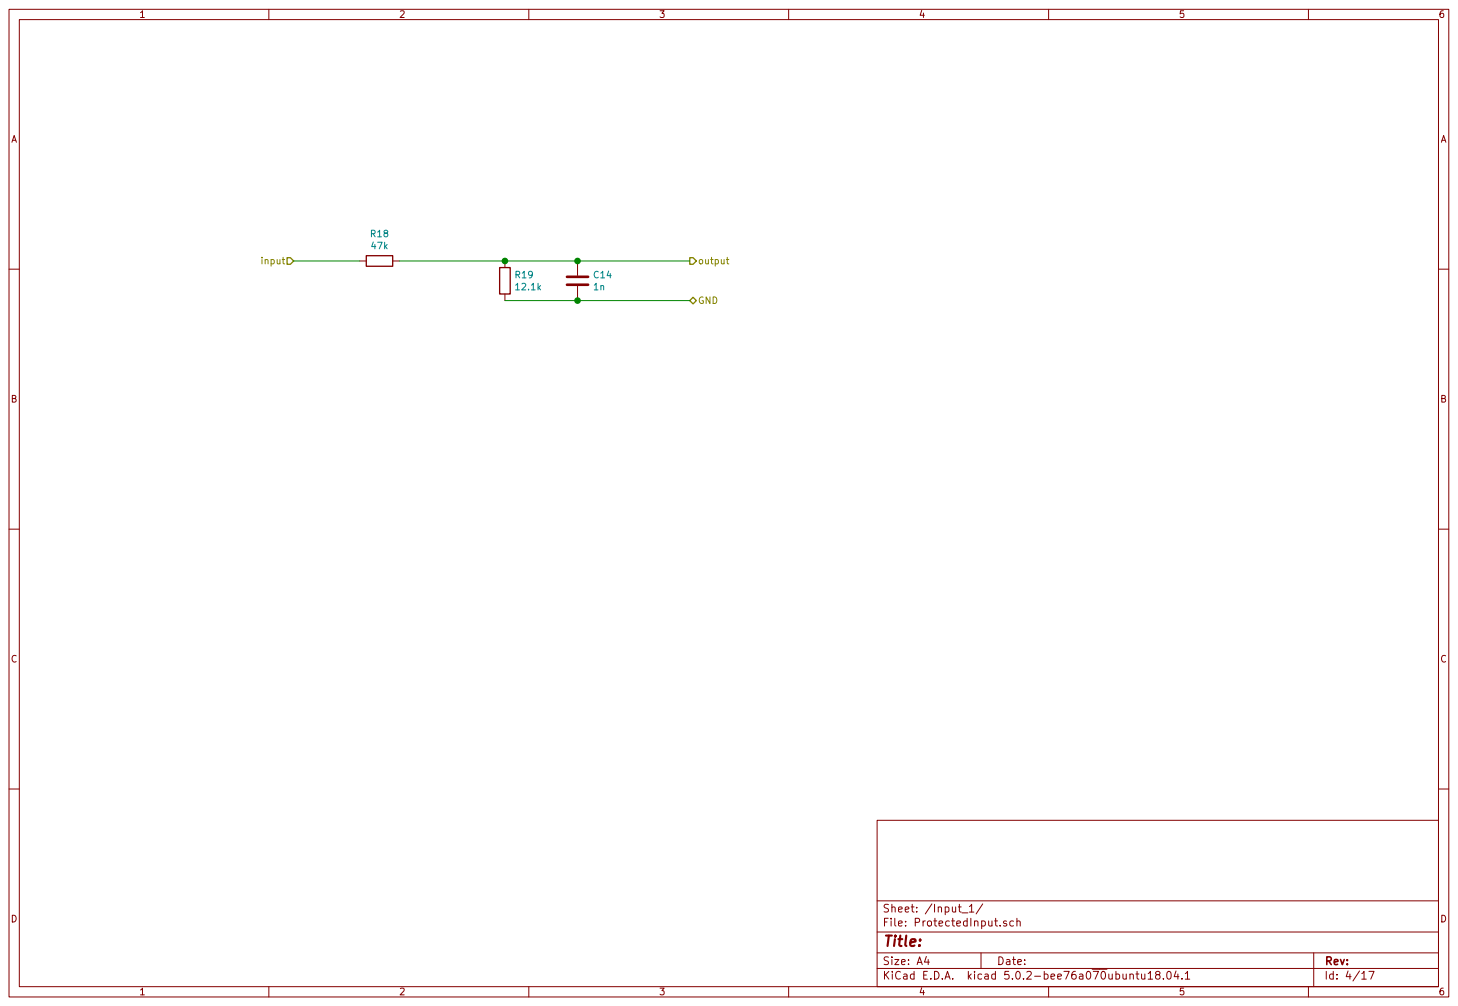
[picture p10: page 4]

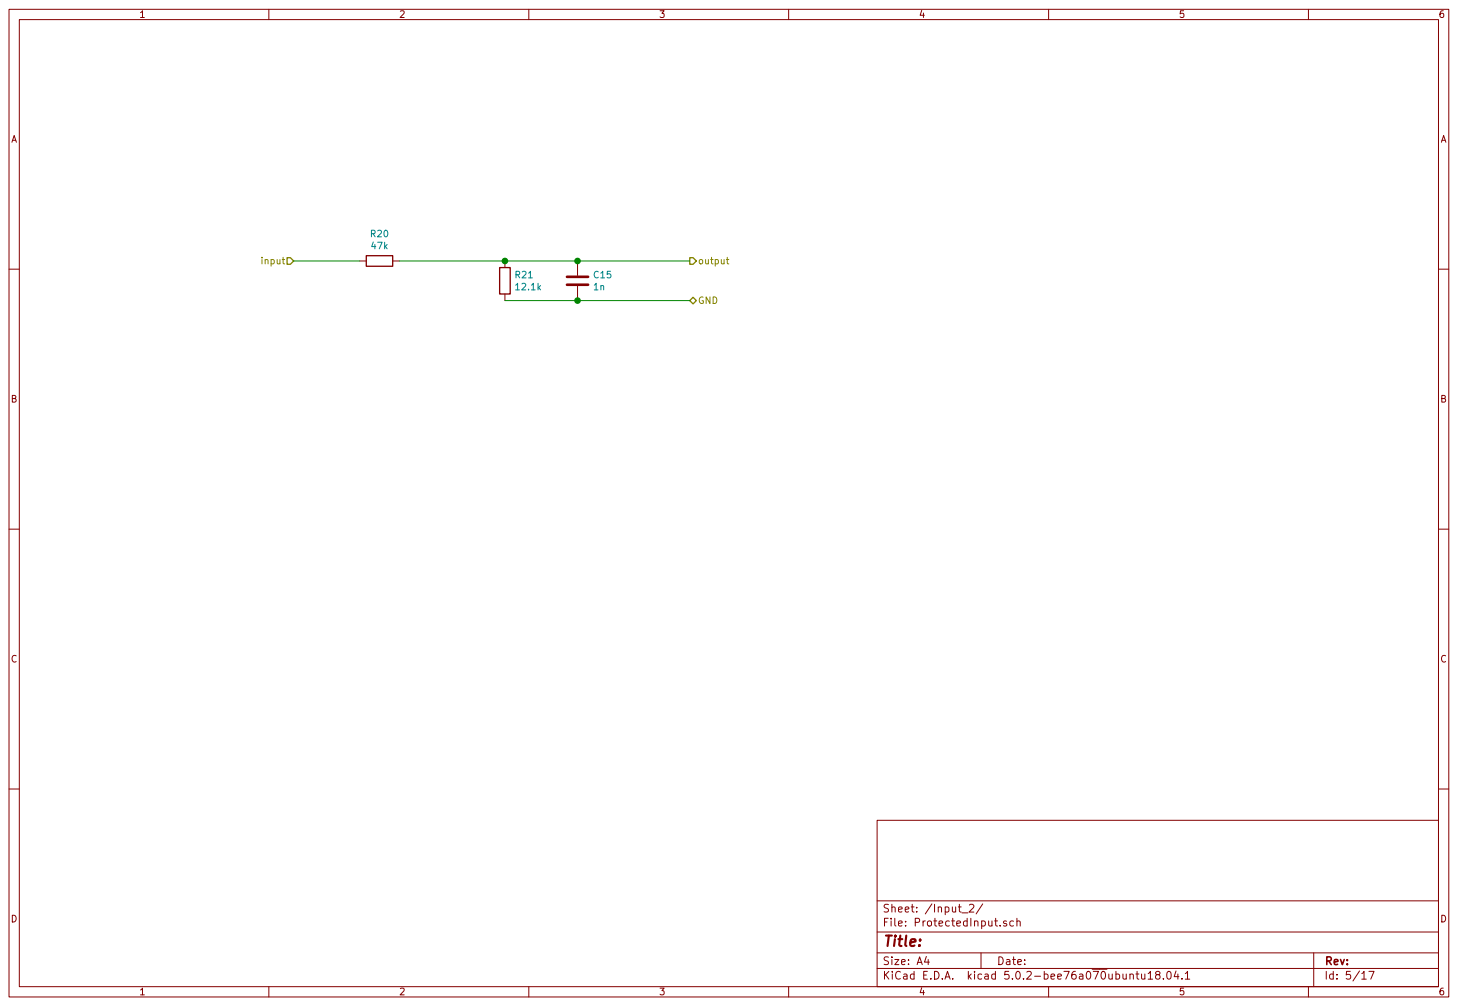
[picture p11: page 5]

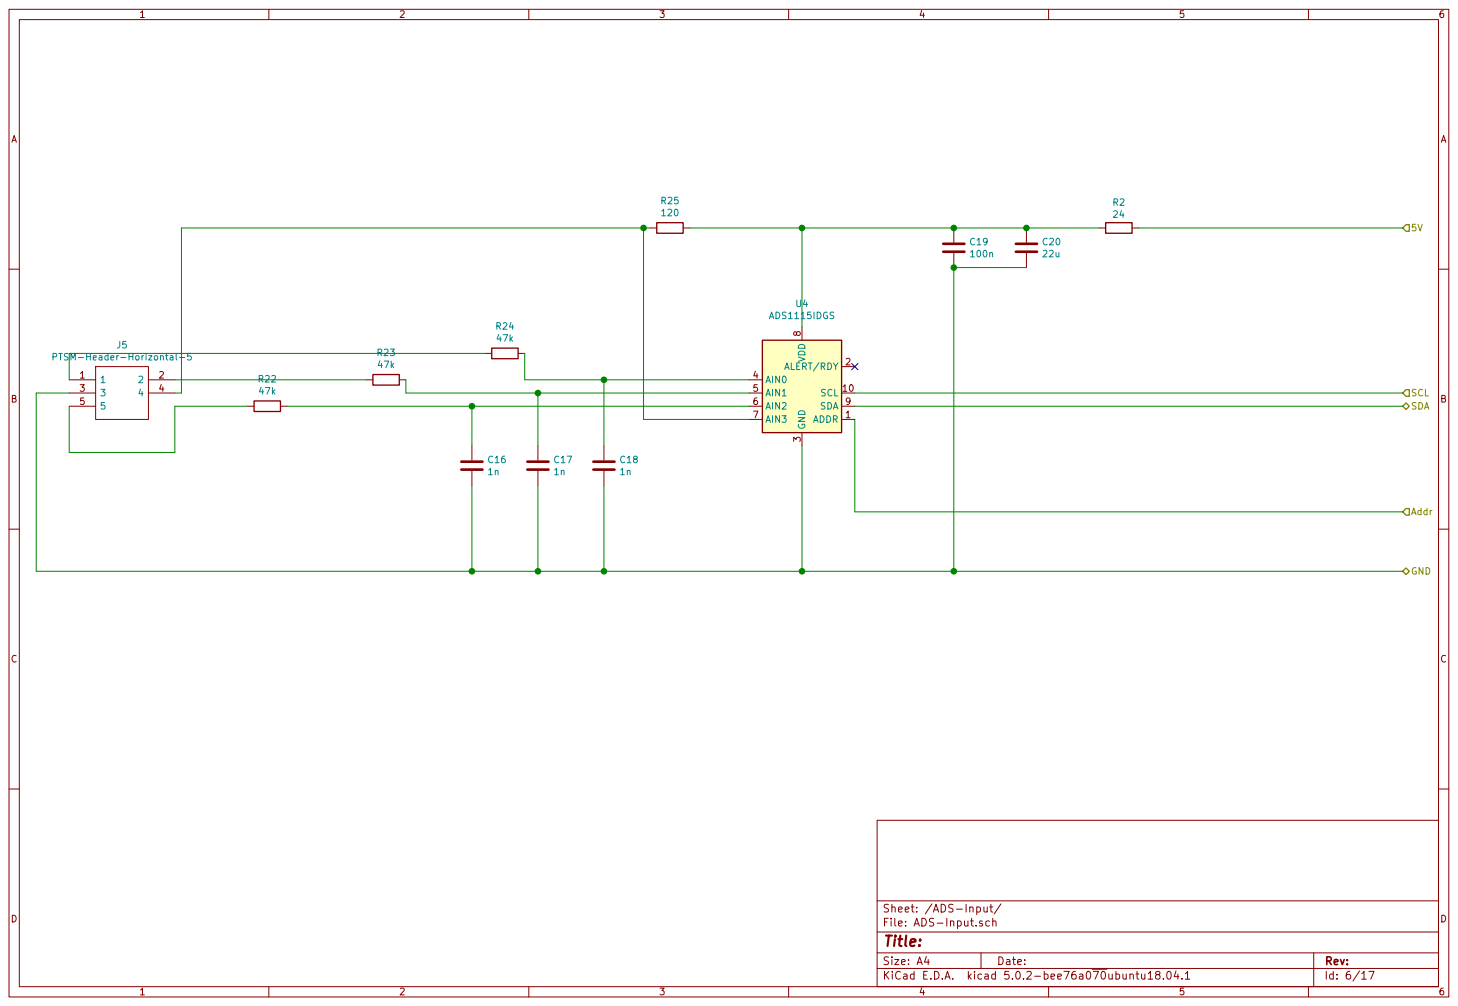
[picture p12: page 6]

File: ADS-Input.sch
Id: 6/17 Title:

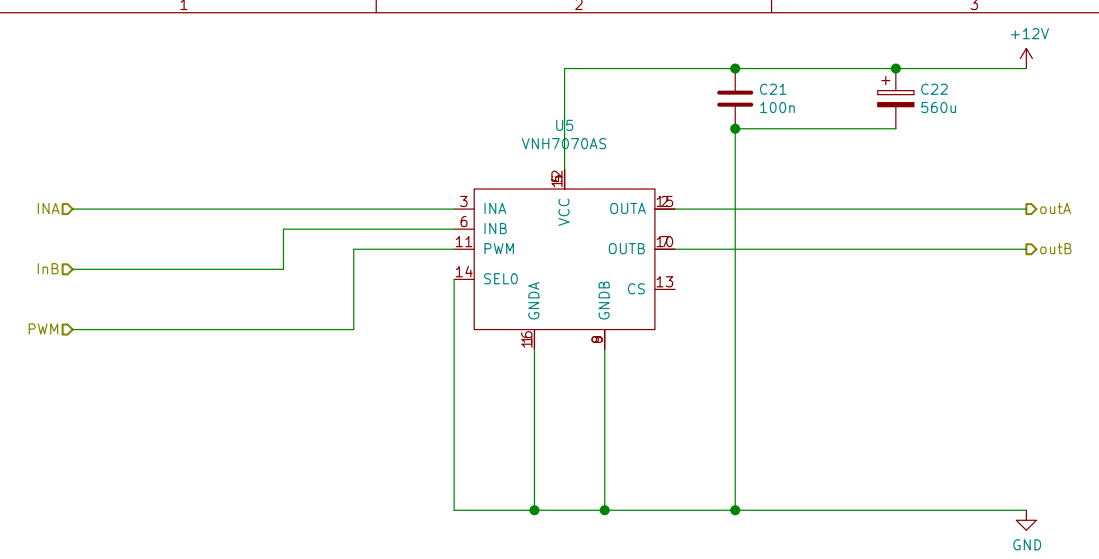
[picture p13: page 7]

Id: 7/17 Title: H-Bridge Motor Driver File: motorDriver.sch Sheet: /motorDriverB/ Based on STM VNH7070ASTR

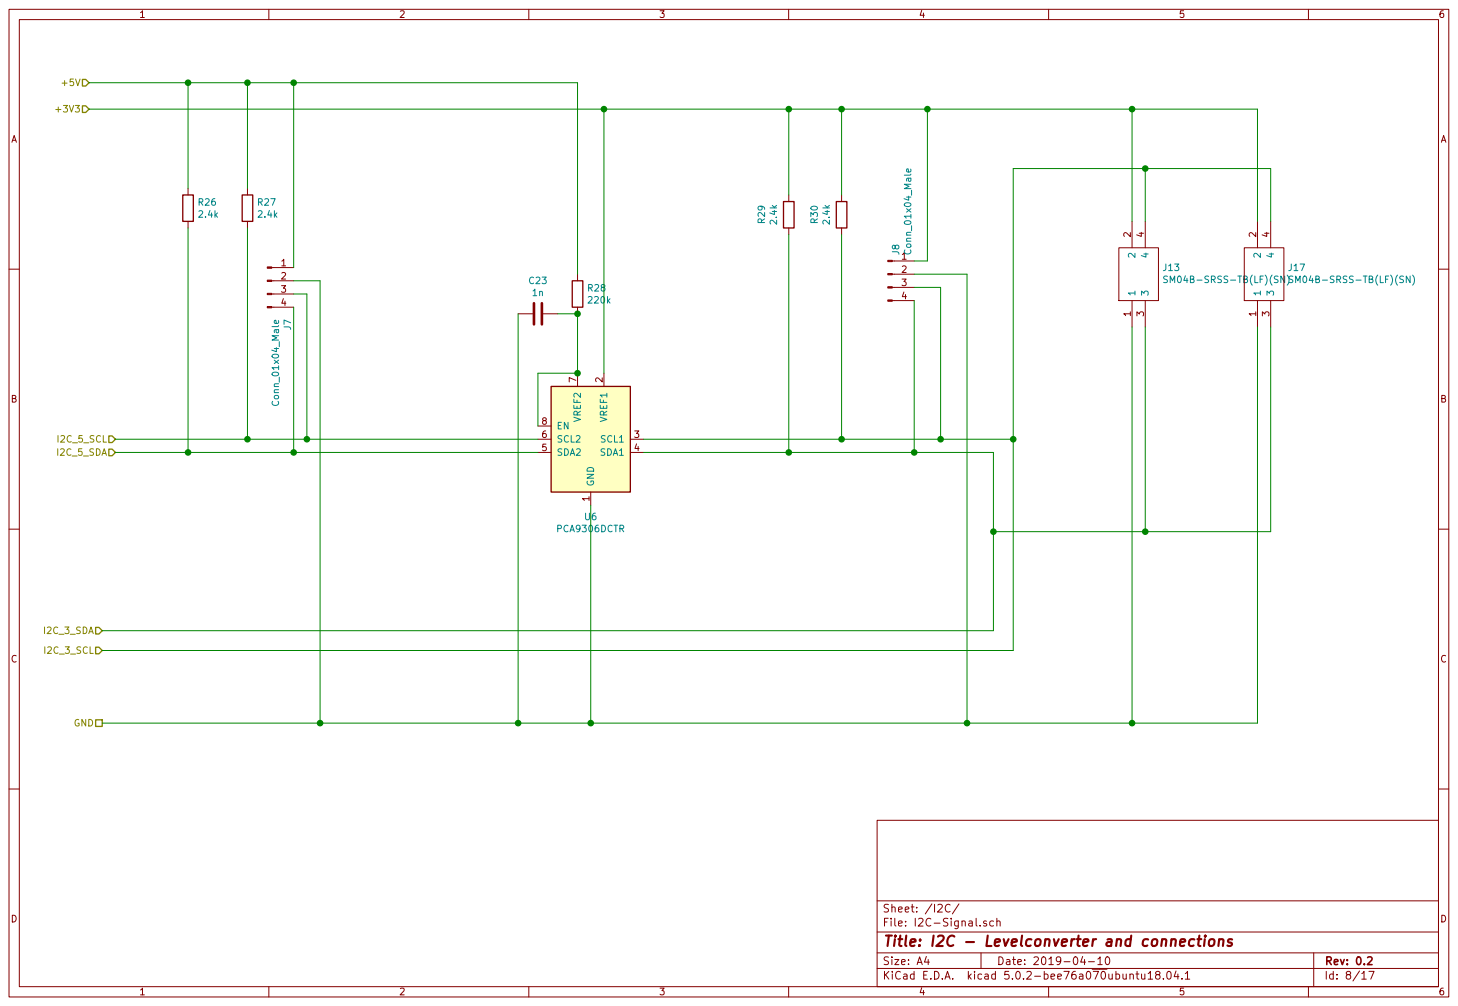
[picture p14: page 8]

J13SM04B-SRSS-TB(LF)(SN) 1

J17SM04B-SRSS-TB(LF)(SN)

File: I2C-Signal.sch Sheet: /I2C/
Id: 8/17 Title: I2C - Levelconverter and connections

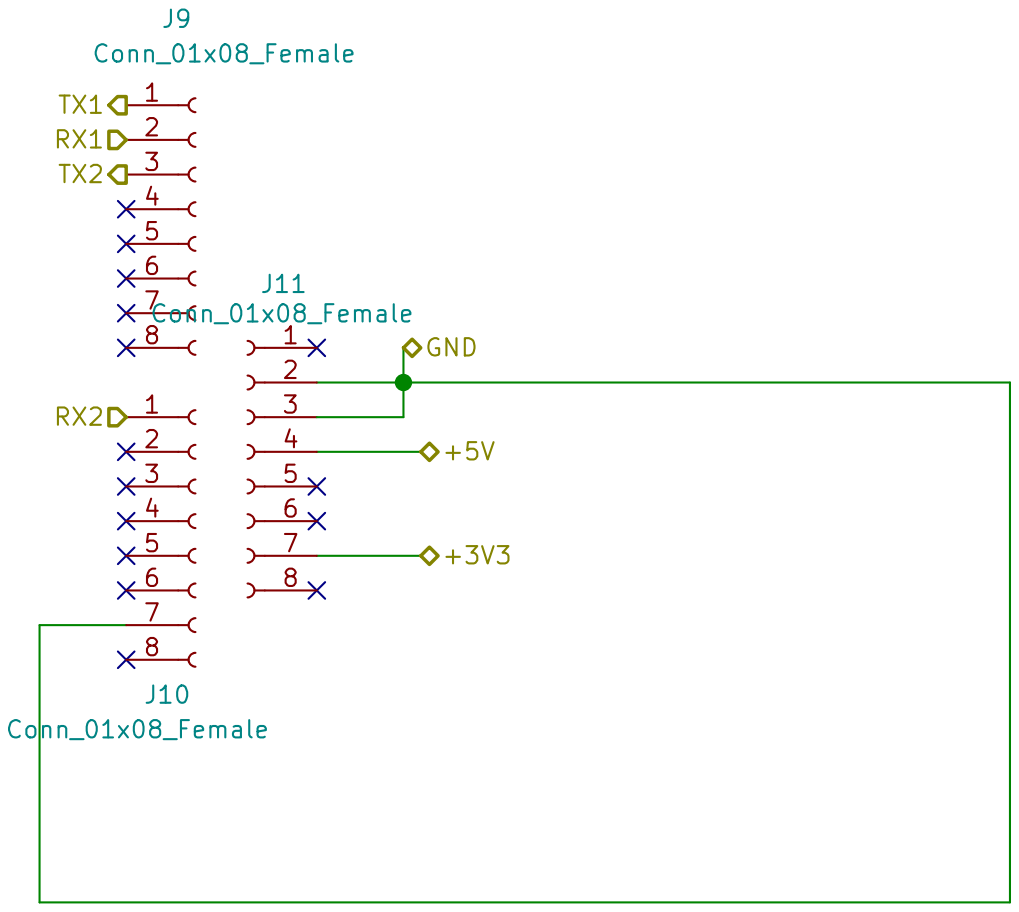
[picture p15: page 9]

Id: 9/17 Title: File: F9P-IO.sch Sheet: /F9P/

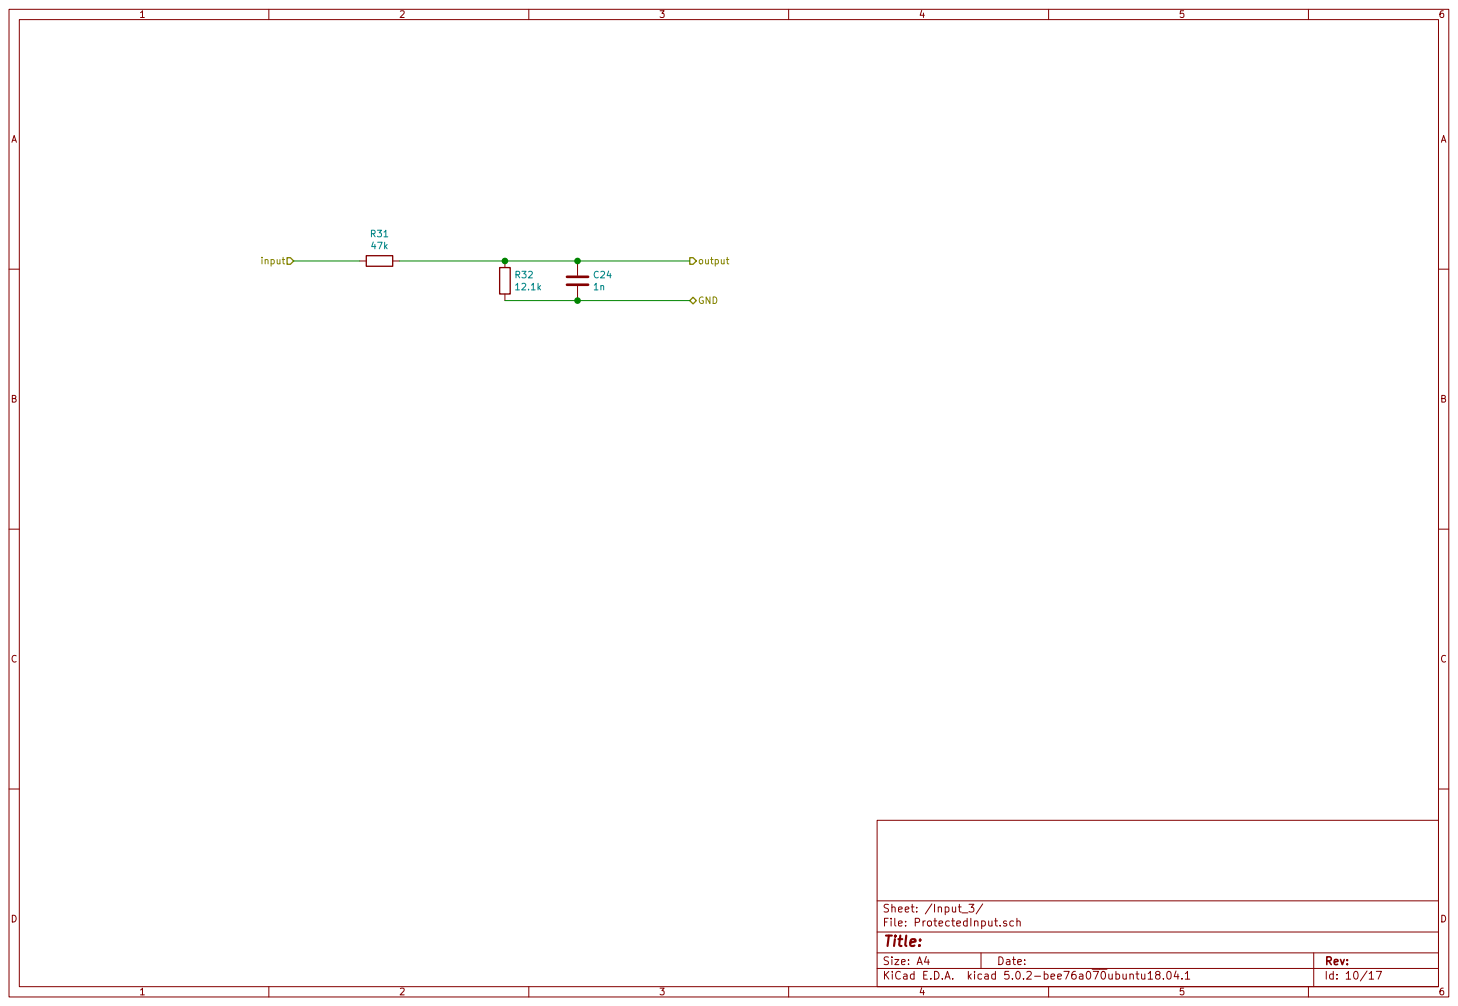
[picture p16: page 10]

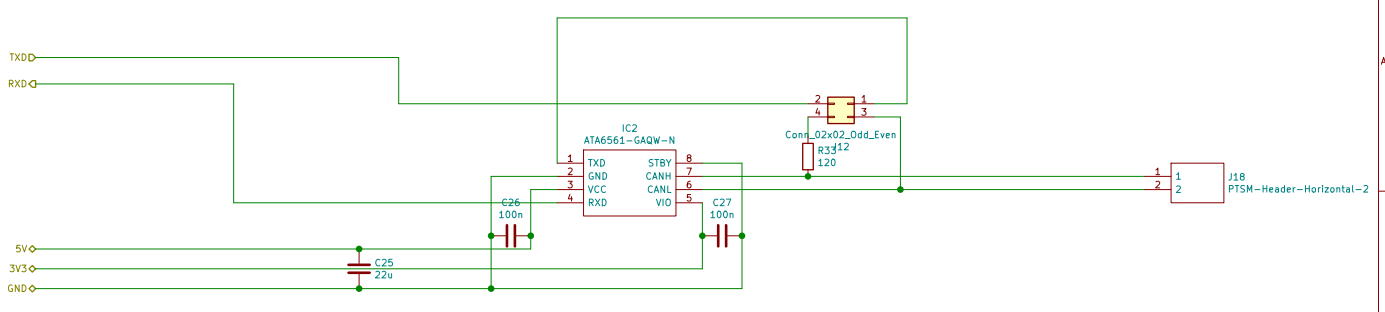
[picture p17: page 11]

Id: 11/17 Title: File: canTransceiver.sch Sheet: /canTransceiver/

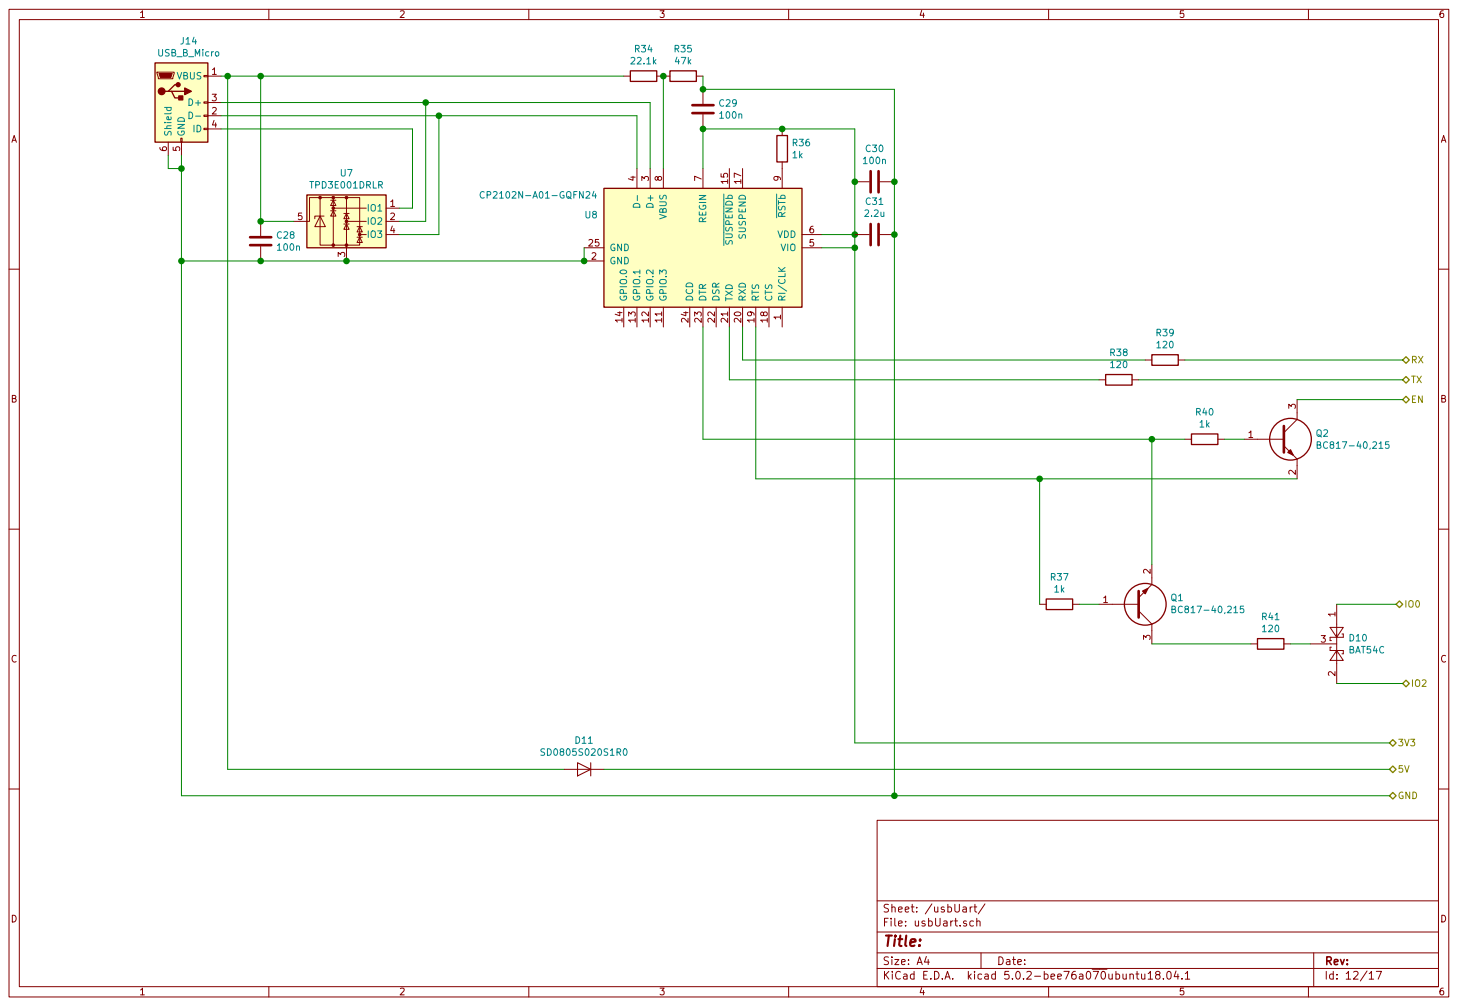
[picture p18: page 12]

1 GPIO.3 11 GPIO.2 12 GPIO.1 13 GPIO.0 14 SUSPENDb 15 SUSPEND 17 CTS 18 RTS 19 GND 2 RXD 20 TXD 21 DSR 22 DTR 23 DCD 24 GND 25 D+

Id: 12/17 Title: File: usbUart.sch Sheet: /usbUart/


Id: 13/17 Title: H-Bridge Motor Driver File: motorDriver.sch Sheet: /sheet5C9DA53F/ Based on STM VNH7070ASTR


Id: 14/17 Title: File: Relais.sch Sheet: /Relais/


Id: 15/17 Title: File: LAN8720.sch Sheet: /LAN8720/


Id: 16/17 Title: File: RS232.sch Sheet: /RS232/


Id: 17/17 Title: File: IMU.sch Sheet: /IMU/

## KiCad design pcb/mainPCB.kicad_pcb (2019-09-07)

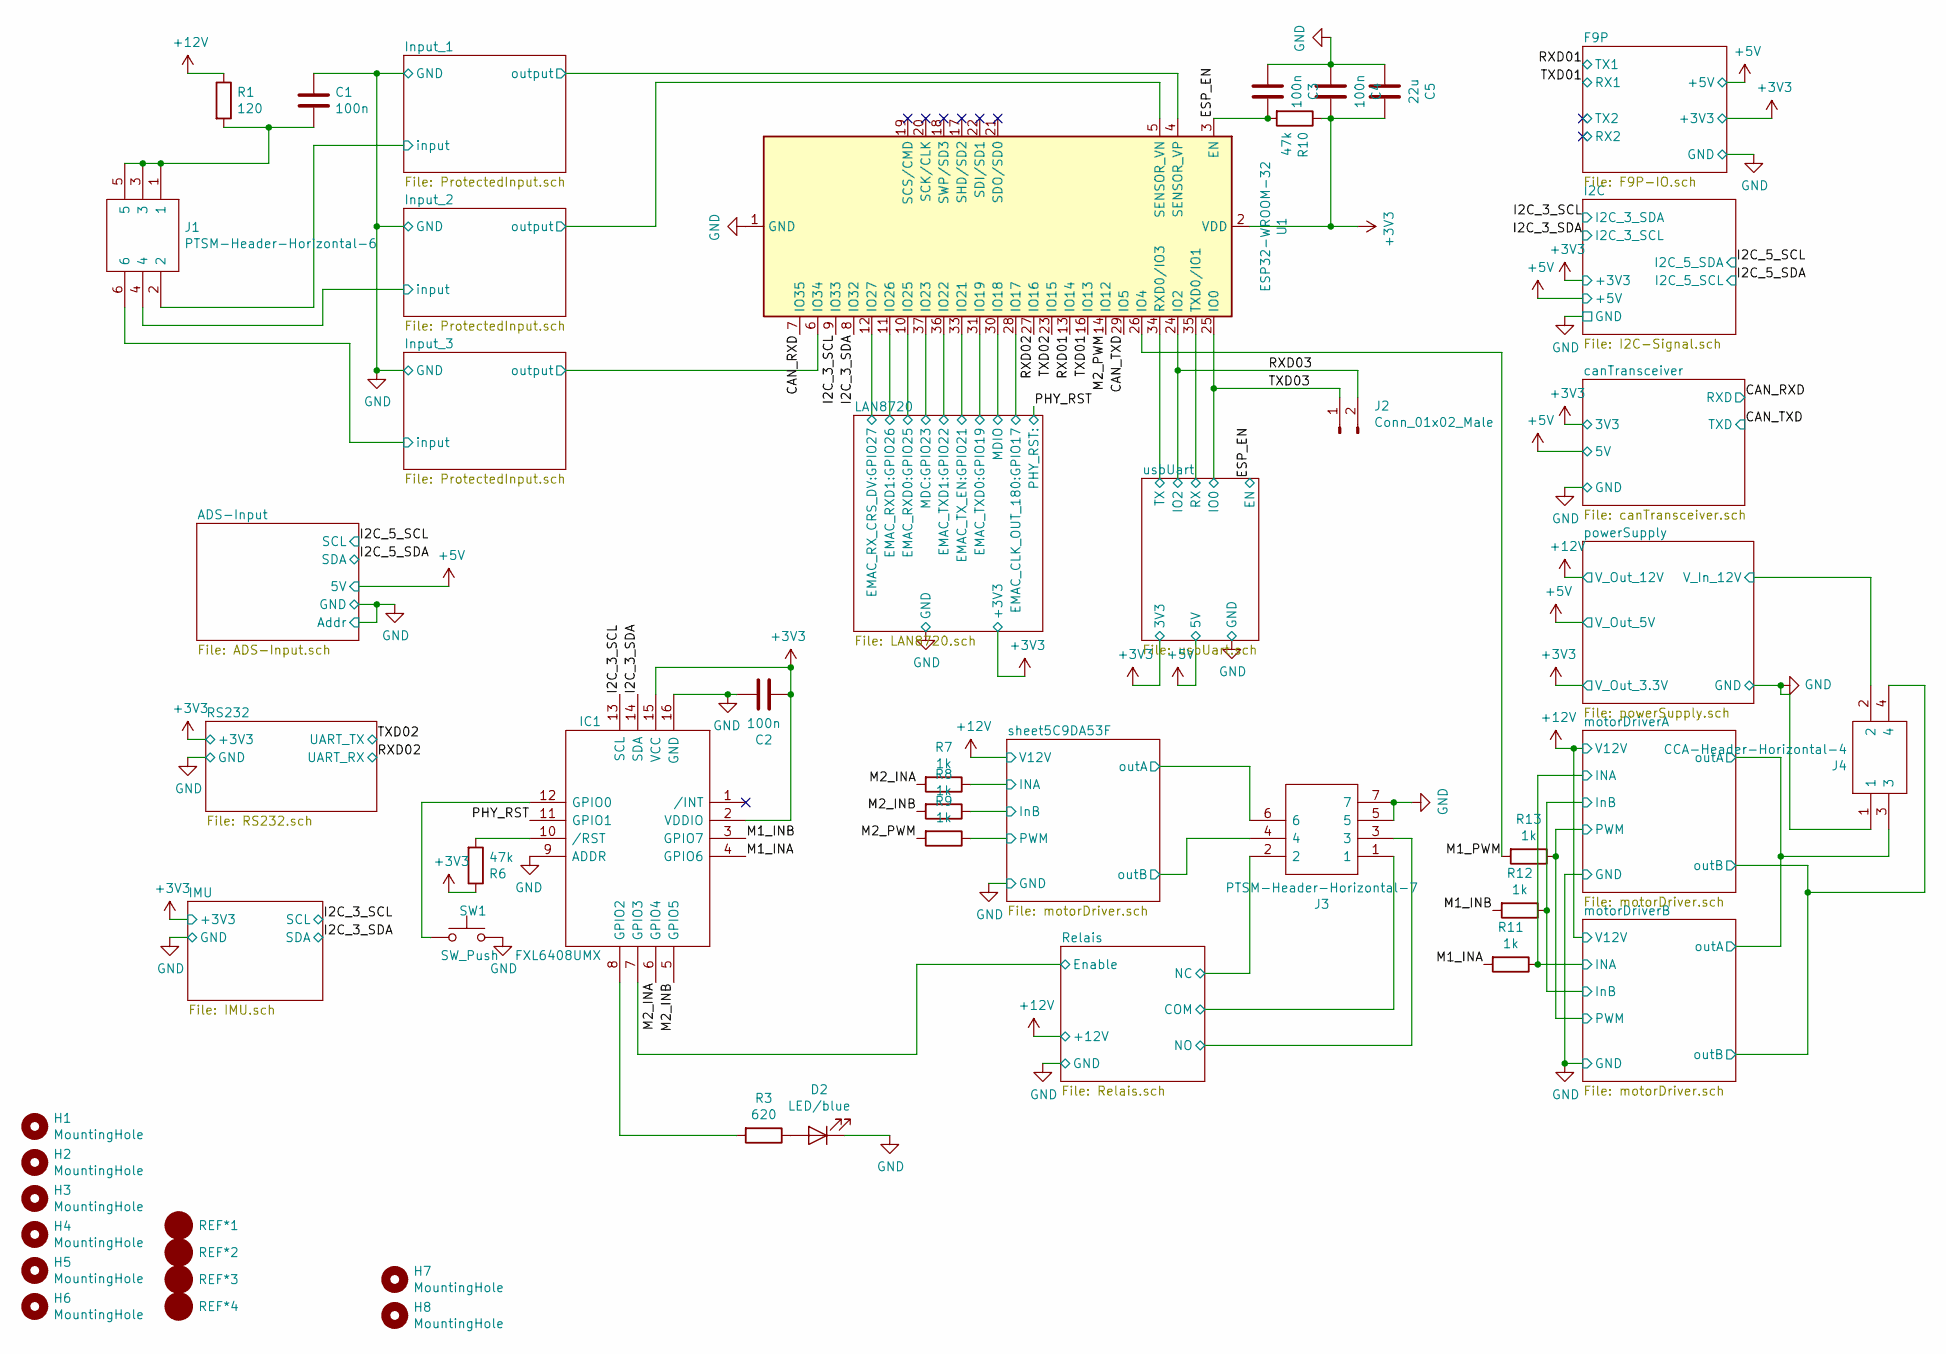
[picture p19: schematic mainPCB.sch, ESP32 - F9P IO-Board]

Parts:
C1, C2, C3, C4: 100n; C_0805_2012Metric
C5: 22u; C_0805_2012Metric
D2: LED/blue; C_0805_2012Metric
H1, H2, H3, H4: MountingHole; MountingHole_4.3mm_M4_DIN965
H5, H6, H7, H8: MountingHole; MountingHole_3.2mm_M3_DIN965
IC1: FXL6408UMX; QFN40P180X260X55-16N; Mouser Part Number 512-FXL6408UMX
J1: PTSM-Header-Horizontal-6; 1814883; Mouser Part Number 651-1814883
J2: Conn_01x02_Male; PinHeader_1x02_P2.54mm_Vertical
J3: PTSM-Header-Horizontal-7; 1814896; Mouser Part Number 651-1814896
J4: CCA-Header-Horizontal-4; 1836366; Manufacturer_Part_Number 1836366; Mouser Part Number 651-1836366
R1: 120; R_0805_2012Metric
R3: 620; R_0805_2012Metric
R6, R10: 47k; R_0805_2012Metric
R7, R8, R9, R11, R12, R13: 1k; R_0805_2012Metric
REF*1, REF*2, REF*3, REF*4: Fiducial; Fiducial_1mm_Dia_2mm_Outer
SW1: SW_Push; SW_SPST_PTS645
U1: ESP32-WROOM-32

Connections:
+3V3: C2.1, C4.1, C5.1, IC1.2 (VDDIO), IC1.15 (VCC), R6.1, R10.1, U1.2 (VDD); also elsewhere on the board
+12V: R1.1; also elsewhere on the board
/CAN_RXD: U1.7 (IO35); also elsewhere on the board
/CAN_TXD: U1.29 (IO5); also elsewhere on the board
/ESP_EN: C3.1, R10.2, U1.3 (EN); also elsewhere on the board
/I2C_3_SCL: IC1.13 (SCL), U1.9 (IO33); also elsewhere on the board
/I2C_3_SDA: IC1.14 (SDA), U1.8 (IO32); also elsewhere on the board
/Input_1/input: J1.2; also elsewhere on the board
/Input_1/output: U1.4 (SENSOR_VP); also elsewhere on the board
/Input_2/input: J1.4; also elsewhere on the board
/Input_2/output: U1.5 (SENSOR_VN); also elsewhere on the board
/Input_3/input: J1.6; also elsewhere on the board
/Input_3/output: U1.6 (IO34); also elsewhere on the board
/LAN8720/EMAC_CLK_OUT_180:GPIO17: U1.28 (IO17); also elsewhere on the board
/LAN8720/EMAC_RXD0:GPIO25: U1.10 (IO25); also elsewhere on the board
/LAN8720/EMAC_RXD1:GPIO26: U1.11 (IO26); also elsewhere on the board
/LAN8720/EMAC_RX_CRS_DV:GPIO27: U1.12 (IO27); also elsewhere on the board
/LAN8720/EMAC_TXD0:GPIO19: U1.31 (IO19); also elsewhere on the board
/LAN8720/EMAC_TXD1:GPIO22: U1.36 (IO22); also elsewhere on the board
/LAN8720/EMAC_TX_EN:GPIO21: U1.33 (IO21); also elsewhere on the board
/LAN8720/MDC:GPIO23: U1.37 (IO23); also elsewhere on the board
/LAN8720/MDIO: U1.30 (IO18); also elsewhere on the board
/M1_INA: IC1.4 (GPIO6), R11.2
/M1_INB: IC1.3 (GPIO7), R12.2
/M1_PWM: R13.2, U1.26 (IO4)
/M2_INA: IC1.6 (GPIO4), R7.2
/M2_INB: IC1.5 (GPIO5), R8.2
/M2_PWM: R9.2, U1.14 (IO12)
/PHY_RST: IC1.11 (GPIO1); also elsewhere on the board
/RXD01: U1.13 (IO14); also elsewhere on the board
/RXD02: U1.27 (IO16); also elsewhere on the board
/RXD03: J2.2, U1.24 (IO2); also elsewhere on the board
/Relais/COM: J3.1; also elsewhere on the board
/Relais/Enable: IC1.7 (GPIO3); also elsewhere on the board
/Relais/NC: J3.2; also elsewhere on the board
/Relais/NO: J3.3; also elsewhere on the board
/TXD01: U1.16 (IO13); also elsewhere on the board
/TXD02: U1.23 (IO15); also elsewhere on the board
/TXD03: J2.1, U1.25 (IO0); also elsewhere on the board
/motorDriverA/INA: R11.1; also elsewhere on the board
/motorDriverA/InB: R12.1; also elsewhere on the board
/motorDriverA/PWM: R13.1; also elsewhere on the board
/motorDriverA/outA: J4.3; also elsewhere on the board
/motorDriverA/outB: J4.4; also elsewhere on the board
/powerSupply/V_In_12V: J4.2; also elsewhere on the board
/sheet5C9DA53F/INA: R7.1; also elsewhere on the board
/sheet5C9DA53F/InB: R8.1; also elsewhere on the board
/sheet5C9DA53F/PWM: R9.1; also elsewhere on the board
/sheet5C9DA53F/outA: J3.6; also elsewhere on the board
/sheet5C9DA53F/outB: J3.4; also elsewhere on the board
/usbUart/RX: U1.35 (TXD0/IO1); also elsewhere on the board
/usbUart/TX: U1.34 (RXD0/IO3); also elsewhere on the board
GND: C1.1, C2.2, C3.2, C4.2, C5.2, D2.1 (K), IC1.9 (ADDR), IC1.16 (GND), J3.5, J3.7, J4.1, SW1.2, U1.1 (GND), U1.15 (GND), U1.38 (GND); also elsewhere on the board
unnamed: C1.2, J1.1, J1.3, J1.5, R1.2
unnamed: D2.2 (A), R3.1
unnamed: IC1.8 (GPIO2), R3.2
unnamed: IC1.10 (/RST), R6.2
unnamed: IC1.12 (GPIO0), SW1.1

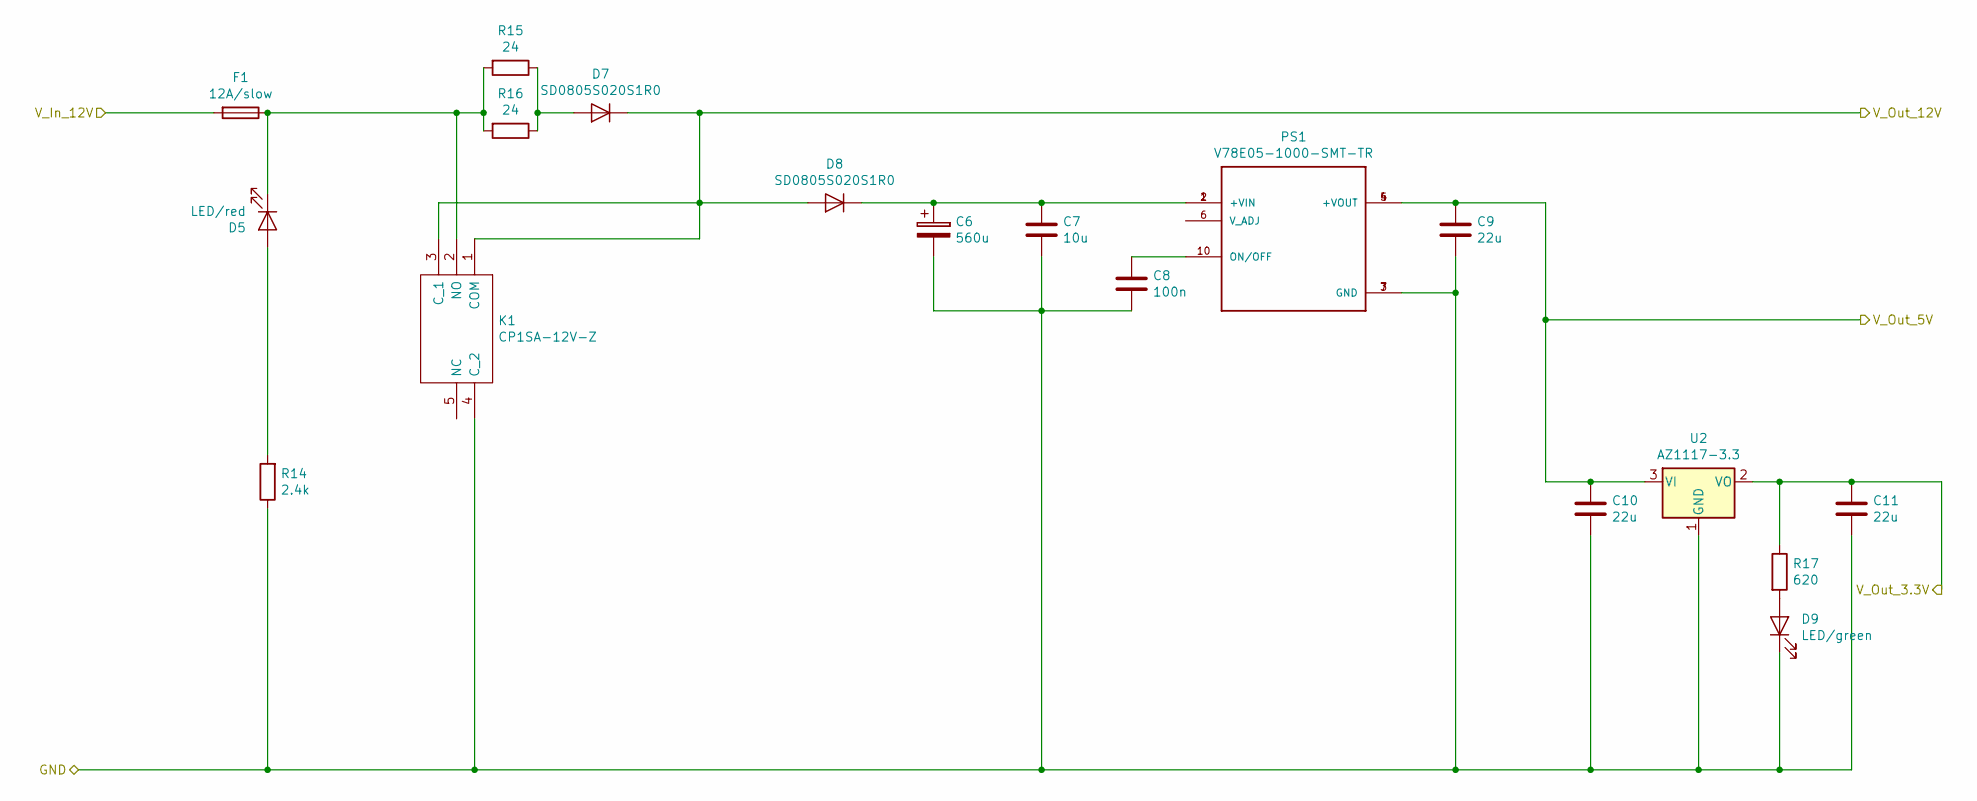
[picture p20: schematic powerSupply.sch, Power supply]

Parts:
C6: 560u; CP_Elec_10x10.5
C7: 10u; C_0805_2012Metric
C8: 100n; C_0805_2012Metric
C9, C10, C11: 22u; C_0805_2012Metric
D5: LED/red; C_0805_2012Metric
D7, D8: SD0805S020S1R0; D_0805_2012Metric
D9: LED/green; C_0805_2012Metric
F1: 12A/slow; Fuse_1206_3216Metric
K1: CP1SA-12V-Z; CP1SA12VZ; Mouser Part Number 769-CP1SA-12V-Z
PS1: V78E05-1000-SMT-TR; SOP254P1140X825-10N
R14: 2.4k; R_0805_2012Metric
R15, R16: 24; R_0805_2012Metric
R17: 620; R_0805_2012Metric
U2: AZ1117-3.3; SOT-223-3_TabPin2

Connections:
+3V3: C11.1, R17.1, U2.2 (VO); also elsewhere on the board
+5V: C9.1, C10.1, PS1.4 (+VOUT), PS1.5 (+VOUT), U2.3 (VI); also elsewhere on the board
+12V: D7.1 (K), D8.2 (A), K1.1 (COM), K1.3 (C_1); also elsewhere on the board
/powerSupply/V_In_12V: F1.2; also elsewhere on the board
GND: C6.2, C7.2, C8.2, C9.2, C10.2, C11.2, D9.1 (K), K1.4 (C_2), PS1.3 (GND), PS1.7 (GND), R14.1, U2.1 (GND); also elsewhere on the board
unnamed: C6.1, C7.1, D8.1 (K), PS1.1 (+VIN), PS1.2 (+VIN)
unnamed: C8.1, PS1.10 (ON/OFF)
unnamed: D5.1 (K), F1.1, K1.2 (NO), R15.2, R16.2
unnamed: D5.2 (A), R14.2
unnamed: D7.2 (A), R15.1, R16.1
unnamed: D9.2 (A), R17.2

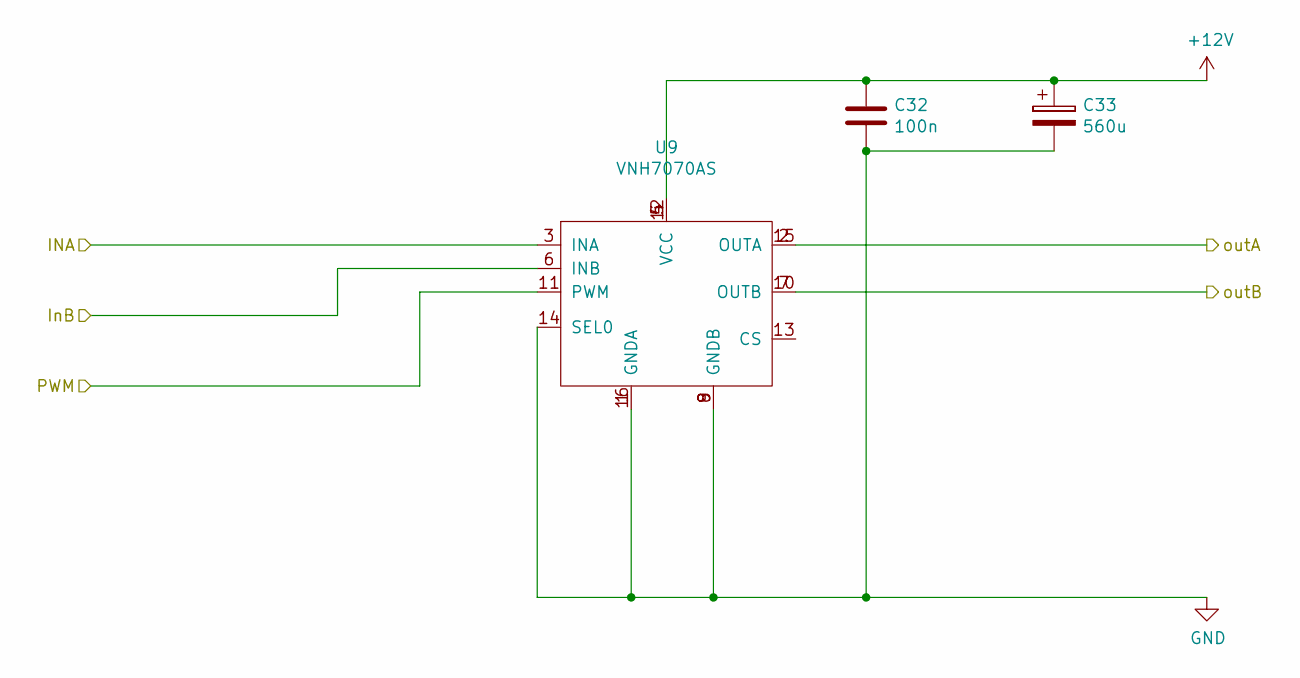
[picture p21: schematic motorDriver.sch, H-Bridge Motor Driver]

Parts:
C12: 100n; C_0805_2012Metric
C13: 560u; CP_Elec_10x10.5
U3: VNH7070AS; SOIC-16_3.9x9.9mm_P1.27mm

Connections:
+12V: C12.1, C13.1, U3.4 (VCC), U3.5 (VCC), U3.12 (VCC); also elsewhere on the board
/motorDriverA/INA: U3.3 (INA); also elsewhere on the board
/motorDriverA/InB: U3.6 (INB); also elsewhere on the board
/motorDriverA/PWM: U3.11 (PWM); also elsewhere on the board
/motorDriverA/outA: U3.2 (OUTA), U3.15 (OUTA); also elsewhere on the board
/motorDriverA/outB: U3.7 (OUTB), U3.10 (OUTB); also elsewhere on the board
GND: C12.2, C13.2, U3.1 (GNDA), U3.8 (GNDB), U3.9 (GNDB), U3.14 (SEL0), U3.16 (GNDA); also elsewhere on the board

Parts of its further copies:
C21, C32: 100n; C_0805_2012Metric
C22, C33: 560u; CP_Elec_10x10.5
U5, U9: VNH7070AS; SOIC-16_3.9x9.9mm_P1.27mm

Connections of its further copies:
+12V: C21.1, C22.1, C32.1, C33.1, U5.4 (VCC), U5.5 (VCC), U5.12 (VCC), U9.4 (VCC), U9.5 (VCC), U9.12 (VCC); also elsewhere on the board
/motorDriverA/INA: U5.3 (INA); also elsewhere on the board
/motorDriverA/InB: U5.6 (INB); also elsewhere on the board
/motorDriverA/PWM: U5.11 (PWM); also elsewhere on the board
/motorDriverA/outA: U5.2 (OUTA), U5.15 (OUTA); also elsewhere on the board
/motorDriverA/outB: U5.7 (OUTB), U5.10 (OUTB); also elsewhere on the board
/sheet5C9DA53F/INA: U9.3 (INA); also elsewhere on the board
/sheet5C9DA53F/InB: U9.6 (INB); also elsewhere on the board
/sheet5C9DA53F/PWM: U9.11 (PWM); also elsewhere on the board
/sheet5C9DA53F/outA: U9.2 (OUTA), U9.15 (OUTA); also elsewhere on the board
/sheet5C9DA53F/outB: U9.7 (OUTB), U9.10 (OUTB); also elsewhere on the board
GND: C21.2, C22.2, C32.2, C33.2, U5.1 (GNDA), U5.8 (GNDB), U5.9 (GNDB), U5.14 (SEL0), U5.16 (GNDA), U9.1 (GNDA), U9.8 (GNDB), U9.9 (GNDB), U9.14 (SEL0), U9.16 (GNDA); also elsewhere on the board

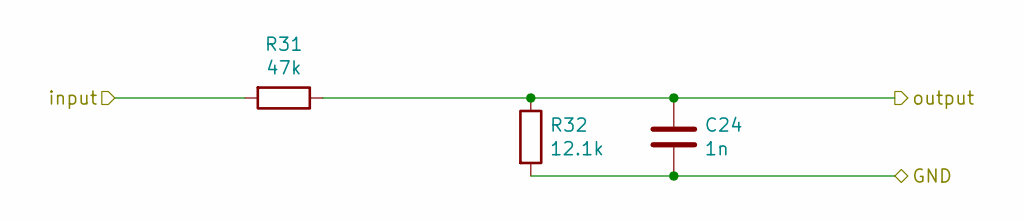
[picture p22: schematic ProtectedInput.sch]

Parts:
C14: 1n; C_0805_2012Metric
R18: 47k; R_0805_2012Metric
R19: 12.1k; R_0805_2012Metric

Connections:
/Input_1/input: R18.2; also elsewhere on the board
/Input_1/output: C14.1, R18.1, R19.1; also elsewhere on the board
GND: C14.2, R19.2; also elsewhere on the board

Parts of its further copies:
C15, C24: 1n; C_0805_2012Metric
R20, R31: 47k; R_0805_2012Metric
R21, R32: 12.1k; R_0805_2012Metric

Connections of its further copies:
/Input_2/input: R20.2; also elsewhere on the board
/Input_2/output: C15.1, R20.1, R21.1; also elsewhere on the board
/Input_3/input: R31.2; also elsewhere on the board
/Input_3/output: C24.1, R31.1, R32.1; also elsewhere on the board
GND: C15.2, C24.2, R21.2, R32.2; also elsewhere on the board

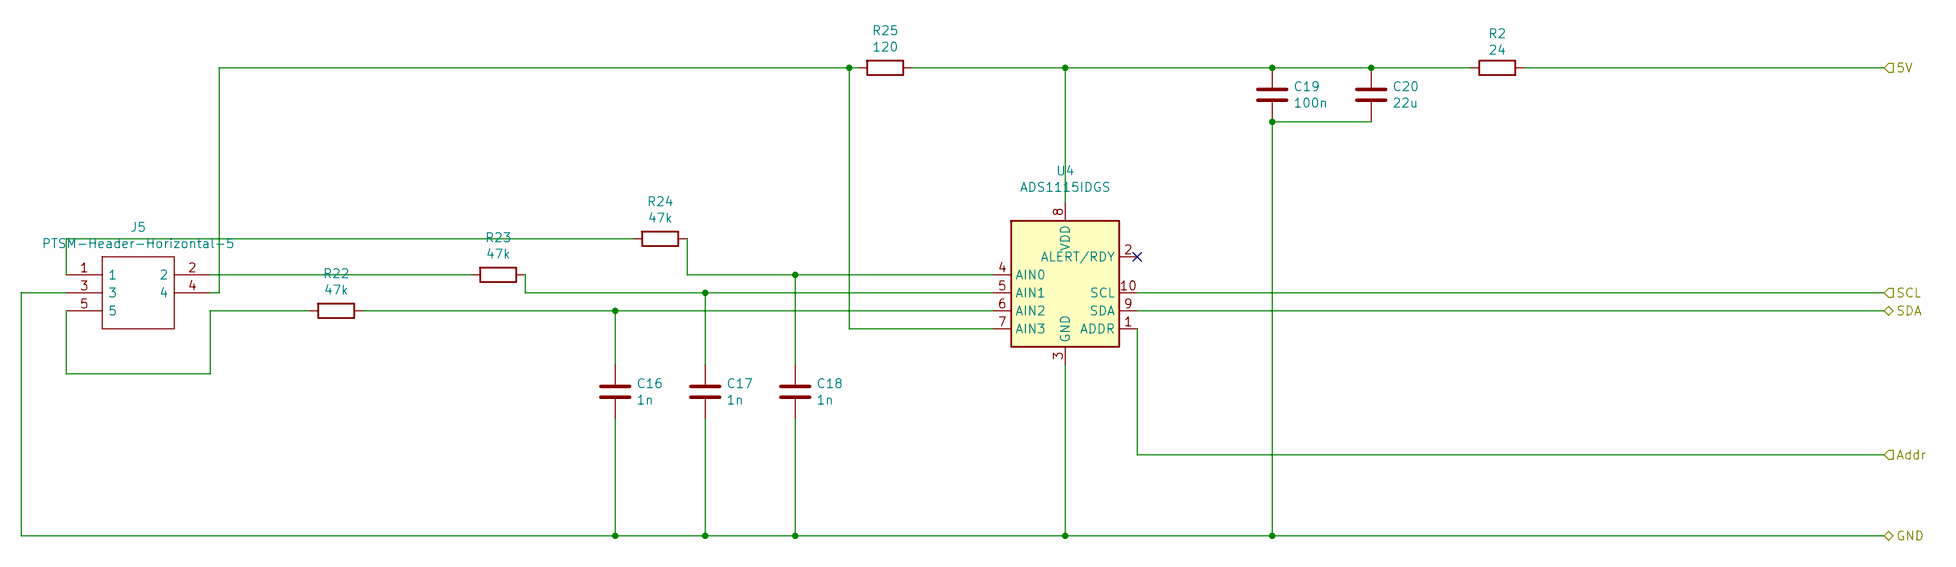
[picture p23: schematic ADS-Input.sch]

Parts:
C16, C17, C18: 1n; C_0805_2012Metric
C19: 100n; C_0805_2012Metric
C20: 22u; C_0805_2012Metric
J5: PTSM-Header-Horizontal-5; 1814870; Mouser Part Number 651-1814870
R2: 24; R_0805_2012Metric
R22, R23, R24: 47k; R_0805_2012Metric
R25: 120; R_0805_2012Metric
U4: ADS1115IDGS; MSOP-10_3x3mm_P0.5mm

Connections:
+5V: R2.2; also elsewhere on the board
/I2C_5_SCL: U4.10 (SCL); also elsewhere on the board
/I2C_5_SDA: U4.9 (SDA); also elsewhere on the board
GND: C16.2, C17.2, C18.2, C19.2, C20.2, J5.3, U4.1 (ADDR), U4.3 (GND); also elsewhere on the board
unnamed: C16.1, R22.1, U4.6 (AIN2)
unnamed: C17.1, R23.1, U4.5 (AIN1)
unnamed: C18.1, R24.1, U4.4 (AIN0)
unnamed: C19.1, C20.1, R2.1, R25.1, U4.8 (VDD)
unnamed: J5.1, R24.2
unnamed: J5.2, R23.2
unnamed: J5.4, R25.2, U4.7 (AIN3)
unnamed: J5.5, R22.2

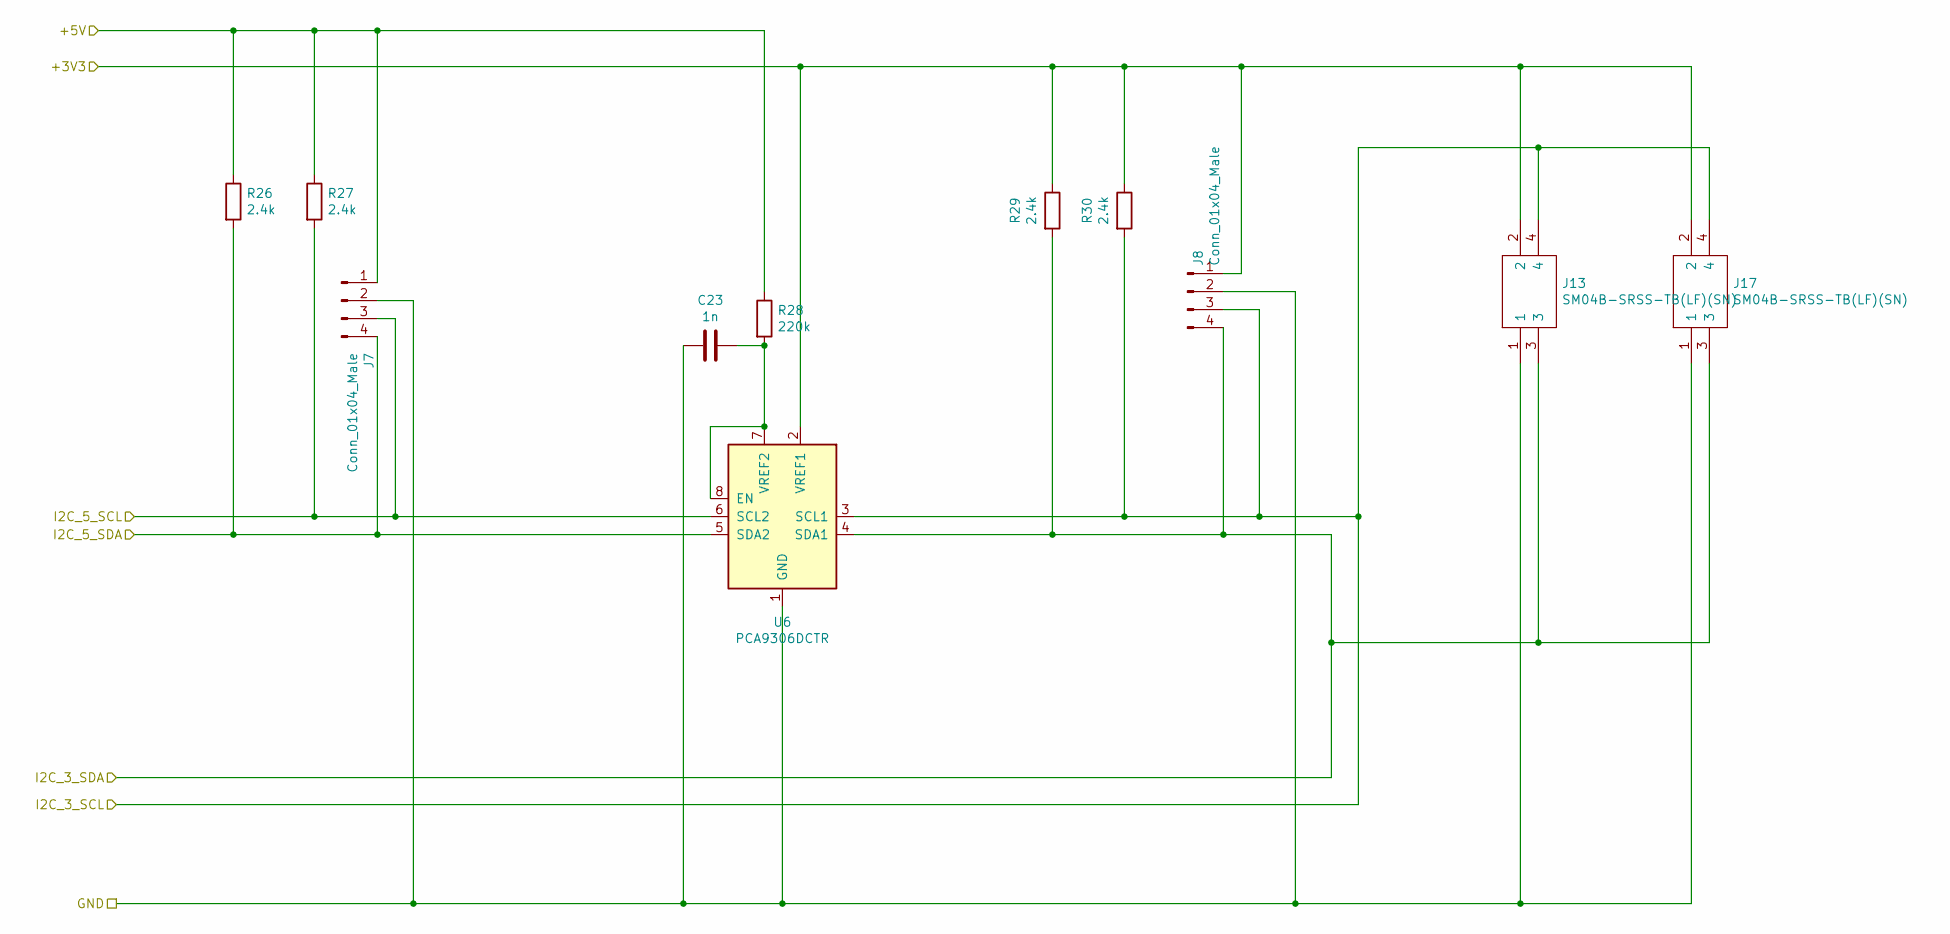
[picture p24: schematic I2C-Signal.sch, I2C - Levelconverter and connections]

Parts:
C23: 1n; C_0805_2012Metric
J7: Conn_01x04_Male; PinHeader_1x04_P2.54mm_Horizontal
J8: Conn_01x04_Male; PinHeader_1x04_P2.54mm_Vertical
J13, J17: SM04B-SRSS-TB(LF)(SN); JST_SH_SM04B-SRSS-TB_1x04-1MP_P1.00mm_Horizontal; Manufacturer_Part_Number SM04B-SRSS-TB(LF)(SN)
R26, R27, R29, R30: 2.4k; R_0805_2012Metric
R28: 220k; R_0805_2012Metric
U6: PCA9306DCTR; SSOP-8_2.95x2.8mm_P0.65mm

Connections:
+3V3: J8.1, J13.2, J17.2, R29.1, R30.1, U6.2 (VREF1); also elsewhere on the board
+5V: J7.1, R26.1, R27.1, R28.1; also elsewhere on the board
/I2C_3_SCL: J8.4, J13.3, J17.3, R29.2, U6.4 (SDA1); also elsewhere on the board
/I2C_3_SDA: J8.3, J13.4, J17.4, R30.2, U6.3 (SCL1); also elsewhere on the board
/I2C_5_SCL: J7.4, R26.2, U6.5 (SDA2); also elsewhere on the board
/I2C_5_SDA: J7.3, R27.2, U6.6 (SCL2); also elsewhere on the board
GND: C23.2, J7.2, J8.2, J13.1, J17.1, U6.1 (GND); also elsewhere on the board
unnamed: C23.1, R28.2, U6.7 (VREF2), U6.8 (EN)

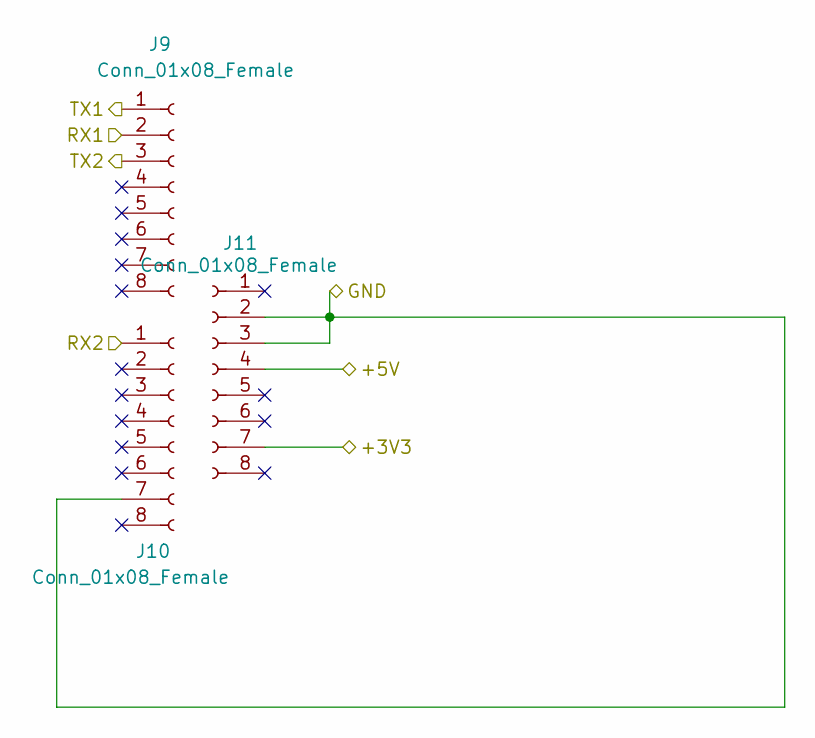
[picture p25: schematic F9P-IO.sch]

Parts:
J9, J10, J11: Conn_01x08_Female; PinSocket_1x08_P2.54mm_Vertical

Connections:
+3V3: J11.7; also elsewhere on the board
+5V: J11.4; also elsewhere on the board
/F9P/RX2: J10.1
/F9P/TX2: J9.3
/RXD01: J9.1; also elsewhere on the board
/TXD01: J9.2; also elsewhere on the board
GND: J10.7, J11.2, J11.3; also elsewhere on the board

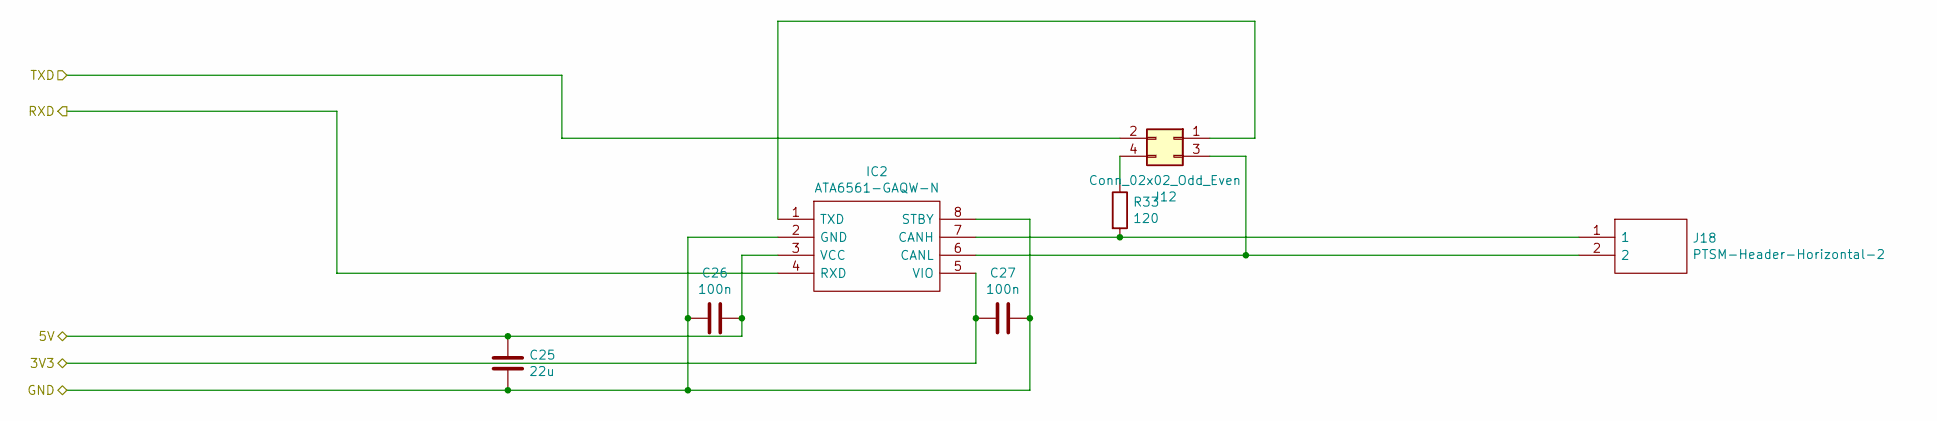
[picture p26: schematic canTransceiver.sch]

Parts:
C25: 22u; C_0805_2012Metric
C26, C27: 100n; C_0805_2012Metric
IC2: ATA6561-GAQW-N; SOIC127P600X175-8N; Mouser Part Number 579-ATA6561-GAQW-N
J12: Conn_02x02_Odd_Even; PinHeader_2x02_P2.54mm_Horizontal
J18: PTSM-Header-Horizontal-2; 1814841; Mouser Part Number 651-1814841
R33: 120; R_0805_2012Metric

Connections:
+3V3: C27.2, IC2.5 (VIO); also elsewhere on the board
+5V: C25.1, C26.1, IC2.3 (VCC); also elsewhere on the board
/CAN_RXD: IC2.4 (RXD); also elsewhere on the board
/CAN_TXD: J12.2; also elsewhere on the board
GND: C25.2, C26.2, C27.1, IC2.2 (GND), IC2.8 (STBY); also elsewhere on the board
unnamed: IC2.1 (TXD), J12.1
unnamed: IC2.6 (CANL), J12.3, J18.2
unnamed: IC2.7 (CANH), J18.1, R33.2
unnamed: J12.4, R33.1

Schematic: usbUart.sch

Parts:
C28, C29, C30: 100n; C_0805_2012Metric
C31: 2.2u; C_0805_2012Metric
D10: BAT54C; SOT-23
D11: SD0805S020S1R0; D_0805_2012Metric
J14: USB_B_Micro; USB_Micro-B_Molex-105017-0001
Q1, Q2: BC817-40,215; SOT95P230X110-3N; Mouser Part Number 771-BC817-40-T/R
R34: 22.1k; R_0805_2012Metric
R35: 47k; R_0805_2012Metric
R36, R37, R40: 1k; R_0805_2012Metric
R38, R39, R41: 120; R_0805_2012Metric
U7: TPD3E001DRLR; SOT-553
U8: CP2102N-A01-GQFN24; QFN-24-1EP_4x4mm_P0.5mm_EP2.6x2.6mm

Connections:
+3V3: C29.2, C30.2, C31.2, R36.1, U8.5 (VIO), U8.6 (VDD), U8.7 (REGIN); also elsewhere on the board
+5V: D11.1 (K); also elsewhere on the board
/ESP_EN: Q2.3; also elsewhere on the board
/RXD03: D10.2; also elsewhere on the board
/TXD03: D10.1; also elsewhere on the board
/usbUart/RX: R39.1; also elsewhere on the board
/usbUart/TX: R38.1; also elsewhere on the board
GND: C28.2, C29.1, C30.1, C31.1, J14.5 (GND), J14.6 (Shield), R35.1, U7.3, U8.2 (GND), U8.25 (GND); also elsewhere on the board
unnamed: C28.1, D11.2 (A), J14.1 (VBUS), R34.2, U7.5
unnamed: D10.3, R41.1
unnamed: J14.2 (D-), U7.4 (IO3), U8.4 (D-)
unnamed: J14.3 (D+), U7.2 (IO2), U8.3 (D+)
unnamed: J14.4 (ID), U7.1 (IO1)
unnamed: Q1.1, R37.1
unnamed: Q1.2, R40.2, U8.23 (DTR)
unnamed: Q1.3, R41.2
unnamed: Q2.1, R40.1
unnamed: Q2.2, R37.2, U8.19 (RTS)
unnamed: R34.1, R35.2, U8.8 (VBUS)
unnamed: R36.2, U8.9 (~RSTb)
unnamed: R38.2, U8.21 (TXD)
unnamed: R39.2, U8.20 (RXD)

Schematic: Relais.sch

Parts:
K2: CP1SA-12V-Z; CP1SA12VZ; Mouser Part Number 769-CP1SA-12V-Z
U10: NUD3124LT1G; SOT95P237X100-3N; Manufacturer_Part_Number NUD3124LT1G

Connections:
+12V: K2.3 (C_1); also elsewhere on the board
/Relais/COM: K2.1 (COM); also elsewhere on the board
/Relais/Enable: U10.1 (GATE); also elsewhere on the board
/Relais/NC: K2.5 (NC); also elsewhere on the board
/Relais/NO: K2.2 (NO); also elsewhere on the board
GND: U10.2 (SOURCE); also elsewhere on the board
unnamed: K2.4 (C_2), U10.3 (DRAIN)

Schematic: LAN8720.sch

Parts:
C34: 1n/2000V; C_1206_3216Metric
C35: 100n/16V; C_0805_2012Metric
C36, C38, C39, C41: 100n; C_0805_2012Metric
C37: 22u; C_0805_2012Metric
C40: 2.2u; C_0805_2012Metric
FB1: 600R/2A; L_0805_2012Metric
J15: RJ45_Amphenol_RJMG1BD3B8K1ANR
R42, R44: 0; R_0805_2012Metric
R43, R50, R51, R52, R53: 2.4k; R_0805_2012Metric
R45, R46, R47, R49: 49.9; R_0805_2012Metric
R48: 12.1k; R_0805_2012Metric
U11: LAN8720A; QFN-24-1EP_4x4mm_P0.5mm_EP2.6x2.6mm

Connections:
+3V3: C41.2, FB1.1, U11.9 (VDDIO); also elsewhere on the board
/LAN8720/+3V3LAN: C36.1, C37.1, C38.1, FB1.2, R44.2, R45.2, R46.2, R47.2, R49.2, R50.2, R51.2, R52.2, R53.2, U11.1 (VDD2A), U11.19 (VDD1A)
/LAN8720/EMAC_CLK_OUT_180:GPIO17: U11.5 (XTAL1/CLKIN); also elsewhere on the board
/LAN8720/EMAC_RXD0:GPIO25: R51.1, U11.8 (RXD0/MODE0); also elsewhere on the board
/LAN8720/EMAC_RXD1:GPIO26: R52.1, U11.7 (RXD1/MODE1); also elsewhere on the board
/LAN8720/EMAC_RX_CRS_DV:GPIO27: R53.1, U11.11 (CRS_DV/MODE2); also elsewhere on the board
/LAN8720/EMAC_TXD0:GPIO19: U11.17 (TXD0); also elsewhere on the board
/LAN8720/EMAC_TXD1:GPIO22: U11.18 (TXD1); also elsewhere on the board
/LAN8720/EMAC_TX_EN:GPIO21: U11.16 (TXEN); also elsewhere on the board
/LAN8720/MDC:GPIO23: U11.13 (MDC); also elsewhere on the board
/LAN8720/MDIO: U11.12 (MDIO); also elsewhere on the board
/LAN8720/RD+: J15.R3 (RD+), R46.1, U11.23 (RXP)
/LAN8720/RD-: J15.R6 (RD-), R49.1, U11.22 (RXN)
/LAN8720/TD-: J15.R2 (TD-), R47.1, U11.20 (TXN)
/PHY_RST: U11.15 (RST); also elsewhere on the board
GND: C35.1, C36.2, C37.2, C38.2, C39.1, C40.1, C41.1, R42.1, R43.2, R48.1, U11.10 (RXER/PHYAD0), U11.25 (VSS); also elsewhere on the board
unnamed: C34.1, J15.R8 (GND), R42.2
unnamed: C34.2, J15.13 (SHIELD)
unnamed: C35.2, J15.R4 (TCT), J15.R5 (RCT), R44.1
unnamed: C39.2, C40.2, U11.6 (VDDCR)
unnamed: J15.L1 (LEDY_A), U11.3 (LED1/REGOFF)
unnamed: J15.L2 (LEDY_K), R43.1
unnamed: J15.L3 (LEDG_K), U11.2 (LED2/nINTSEL)
unnamed: J15.L4 (LEDG_A), R50.1
unnamed: J15.R1 (TD+), R45.1, U11.21 (TXP)
unnamed: R48.2, U11.24 (RBIAS)

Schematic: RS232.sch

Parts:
C42, C43, C44, C45, C46: 100n; C_0805_2012Metric
IC3: ICL3221EIVZ; SOP65P640X120-16N; Manufacturer_Part_Number ICL3221EIVZ
J16: DB9_Male_MountingHoles; LD09P33E4GV00LF

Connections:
+3V3: C46.1, IC3.12 (FORCEON), IC3.15 (VCC), IC3.16 (FORCEOFF); also elsewhere on the board
/RXD02: IC3.9 (R1OUT); also elsewhere on the board
/TXD02: IC3.11 (T1IN); also elsewhere on the board
GND: C42.2, C45.2, C46.2, IC3.1 (EN), IC3.14 (GND), J16.0 (PAD), J16.5; also elsewhere on the board
unnamed: C42.1, IC3.7 (V-)
unnamed: C43.1, IC3.6 (C2-)
unnamed: C43.2, IC3.5 (C2+)
unnamed: C44.1, IC3.4 (C1-)
unnamed: C44.2, IC3.2 (C1+)
unnamed: C45.1, IC3.3 (V+)
unnamed: IC3.8 (R1IN), J16.2
unnamed: IC3.13 (T1OUT), J16.3

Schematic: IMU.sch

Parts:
C47: 10n; C_0805_2012Metric
C48, C49, C51: 100n; C_0805_2012Metric
C50: 10u; C_0805_2012Metric
R54: 24; R_0805_2012Metric
U12: LSM9DS1; LGA-24L_3x3.5mm_P0.43mm

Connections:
+3V3: C49.2, R54.1, U12.1 (VDDIO), U12.3 (VDDIO), U12.7 (CS_A/G), U12.8 (CS_M); also elsewhere on the board
/I2C_3_SCL: U12.2 (SCL/SPC); also elsewhere on the board
/I2C_3_SDA: U12.4 (SDA/SDI/SDO); also elsewhere on the board
GND: C47.1, C48.1, C49.1, C50.1, C51.1, U12.5 (SDO_A/G), U12.6 (SDO_M), U12.14 (RES), U12.15 (RES), U12.16 (RES), U12.17 (RES), U12.18 (RES), U12.19 (GND), U12.20 (GND); also elsewhere on the board
unnamed: C47.2, U12.21 (CAP)
unnamed: C48.2, U12.24 (C1)
unnamed: C50.2, C51.2, R54.2, U12.22 (VDD), U12.23 (VDD)

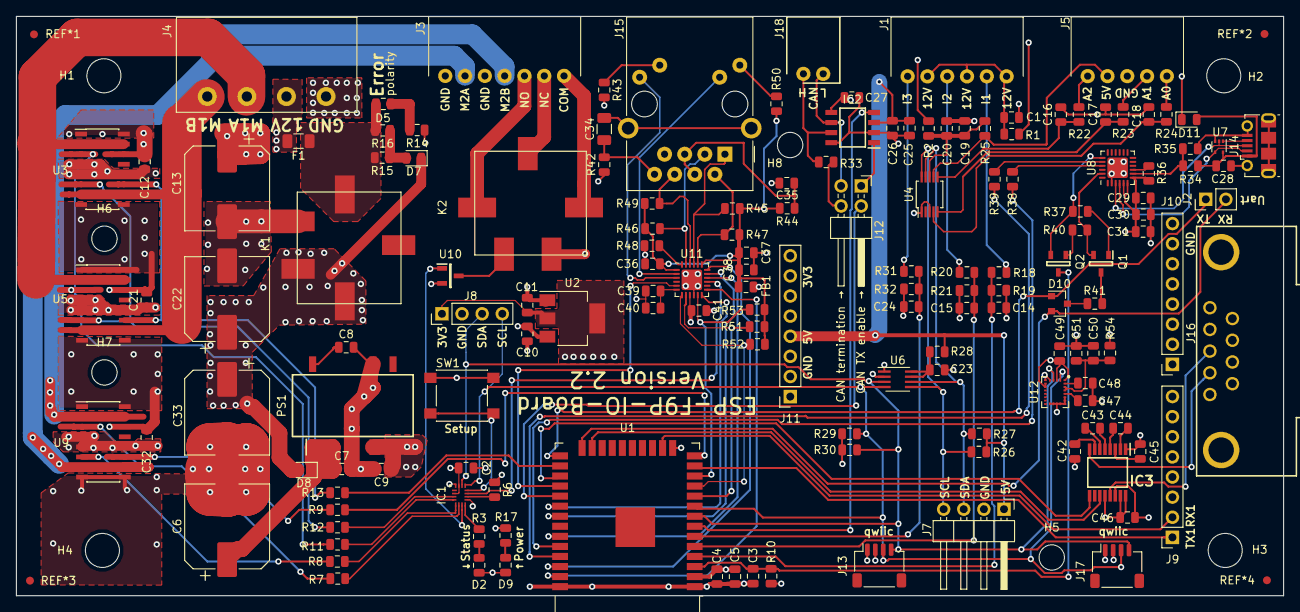
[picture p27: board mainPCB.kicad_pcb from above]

Board: 4 copper layers, 160.0 x 73.2 mm, 158 parts (0 on the bottom side), 120 nets.

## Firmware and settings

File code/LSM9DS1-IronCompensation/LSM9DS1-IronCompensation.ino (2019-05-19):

// calibration after https://appelsiini.net/2018/calibrate-magnetometer/


// IO pins --------------------------------
#define I2C_SDA 32
#define I2C_SCL 33

// includes
#include <Wire.h>
#include <LSM9DS1_Registers.h>
#include <SparkFunLSM9DS1.h>
#include <LSM9DS1_Types.h>

// global variables
float hardIron[3];
float softIron[3];
int gyros[3];

// instances
LSM9DS1 imu;

void setup() {
  //Initialize serial and wait for port to open:
  Serial.begin(115200);
  Serial.println("-------------------------------------");
  Serial.println("ESP32 - LSM9DS1 Hard Iron calibration");
  Serial.println("-------------------------------------");
  Serial.println("");
  Serial.println("After each step press any");
  Serial.println("key is (over serial)");
  Serial.println("");
  // Setup IO

  // I2C
  Wire.begin(I2C_SDA, I2C_SCL, 400000);

  // Setup LSM9DS1
  Serial.println("Konfigure the LSM9DS1");
  imu.settings.device.commInterface = IMU_MODE_I2C;
  imu.settings.device.mAddress = 0x1C;
  imu.settings.device.agAddress = 0x6A;
  imu.settings.mag.scale = 4; // Set mag scale to +/-12 Gs
  // [sampleRate] sets the output data rate (ODR) of the
  // magnetometer.
  // mag data rate can be 0-7:
  // 0 = 0.625 Hz  4 = 10 Hz
  // 1 = 1.25 Hz   5 = 20 Hz
  // 2 = 2.5 Hz    6 = 40 Hz
  // 3 = 5 Hz      7 = 80 Hz
  imu.settings.mag.sampleRate = 5; // Set OD rate to 20Hz
  // [tempCompensationEnable] enables or disables
  // temperature compensation of the magnetometer.
  imu.settings.mag.tempCompensationEnable = true;
  // [XYPerformance] sets the x and y-axis performance of the
  // magnetometer to either:
  // 0 = Low power mode      2 = high performance
  // 1 = medium performance  3 = ultra-high performance
  imu.settings.mag.XYPerformance = 3; // Ultra-high perform.
  // [ZPerformance] does the same thing, but only for the z
  imu.settings.mag.ZPerformance = 3; // Ultra-high perform.
  // [lowPowerEnable] enables or disables low power mode in
  // the magnetometer.
  imu.settings.mag.lowPowerEnable = false;
  if (!imu.begin()) {
    Serial.println("Failed to communicate with LSM9DS1.");
  }

  Serial.println("Leave board in position, no movement (gyro calibration)");
  Serial.println("Press to continue");
  while (Serial.read() == -1 ) {
    delay(1);
  }

  // read 256 Values, then shift 8 bit for correction values
  for (int i = 0; i < 256; i++) {
    imu.readGyro();
    gyros[0] += imu.gx;
    gyros[1] += imu.gy;
    gyros[2] += imu.gz;
    delay(50);
  }
  gyros[0] = gyros[0] >> 8;
  gyros[1] = gyros[1] >> 8;
  gyros[2] = gyros[2] >> 8;

  // Hard iron calibration
  Serial.println("Now: Slowly turn around all axis (magnetometer - iron compensation)");
  Serial.println("After enough turns press any key");
  int calData[3][2] = {{32767, -32767}, {32767, -32767}, {32767, -32767}};

  while (Serial.read() == -1 ) {
    delay(50);
    // To read from the magnetometer, you must first call the
    // readMag() function. When this exits, it'll update the
    // mx, my, and mz variables with the most current data.
    imu.readMag();
    if (imu.mx < calData[0][0]) {
      calData[0][0] = imu.mx;
    }
    if (imu.mx > calData[0][1]) {
      calData[0][1] = imu.mx;
    }
    if (imu.my < calData[1][0]) {
      calData[1][0] = imu.my;
    }
    if (imu.my > calData[1][1]) {
      calData[1][1] = imu.my;
    }
    if (imu.mz < calData[2][0]) {
      calData[2][0] = imu.mz;
    }
    if (imu.mz > calData[2][1]) {
      calData[2][1] = imu.mz;
    }
  }

  // calculate hard iron compensation
  hardIron[0] = (calData[0][0] + calData[0][1]) / 2;
  hardIron[1] = (calData[1][0] + calData[1][1]) / 2;
  hardIron[2] = (calData[2][0] + calData[2][1]) / 2;


  // soft iron

  // apply the hard iron correction on the raw data
  calData[0][0] -= hardIron[0];
  calData[1][0] -= hardIron[1];
  calData[2][0] -= hardIron[2];
  calData[0][1] -= hardIron[0];
  calData[1][1] -= hardIron[1];
  calData[2][1] -= hardIron[2];


  // calculate soft iron data
  softIron[0] = float((calData[0][1] - calData[0][0])) / 2;
  softIron[1] = float((calData[1][1] - calData[1][0])) / 2;
  softIron[2] = float((calData[2][1] - calData[2][0])) / 2;

  float avgDelta = (softIron[0] + softIron[1] + softIron[3]) / 3;

  softIron[0] = avgDelta / softIron[0];
  softIron[1] = avgDelta / softIron[1];
  softIron[2] = avgDelta / softIron[2];
}

int ironCorrction(byte axis, int rawValue) {
  return round((rawValue - hardIron[axis]) * softIron[axis]);
}

void loop() {
  printGyro();  // Print "G: gx, gy, gz"
  printAccel(); // Print "A: ax, ay, az"
  printMag();   // Print "M: mx, my, mz"

  // Print the heading and orientation for fun!
  // Call print attitude. The LSM9DS1's magnetometer x and y
  // axes are opposite to the accelerometer, so my and mx are
  // substituted for each other.
  printAttitude(imu.ax, imu.ay, imu.az, -1 * ironCorrction(1, imu.my), -1 * ironCorrction(0, imu.mx), -1 * ironCorrction(2, imu.mz));
  Serial.println();
  delay(500);

}


void printGyro()
{
  // To read from the gyroscope, you must first call the
  // readGyro() function. When this exits, it'll update the
  // gx, gy, and gz variables with the most current data.
  imu.readGyro();

  // Now we can use the gx, gy, and gz variables as we please.
  // Either print them as raw ADC values, or calculated in DPS.
  Serial.print("G: ");
  // If you want to print calculated values, you can use the
  // calcGyro helper function to convert a raw ADC value to
  // DPS. Give the function the value that you want to convert.
  Serial.print(imu.calcGyro(imu.gx - gyros[0]), 2);
  Serial.print(", ");
  Serial.print(imu.calcGyro(imu.gy - gyros[1]), 2);
  Serial.print(", ");
  Serial.print(imu.calcGyro(imu.gz - gyros[2]), 2);
  Serial.println(" deg/s");
}

void printAccel()
{
  // To read from the accelerometer, you must first call the
  // readAccel() function. When this exits, it'll update the
  // ax, ay, and az variables with the most current data.
  imu.readAccel();

  // Now we can use the ax, ay, and az variables as we please.
  // Either print them as raw ADC values, or calculated in g's.
  Serial.print("A: ");
  // If you want to print calculated values, you can use the
  // calcAccel helper function to convert a raw ADC value to
  // g's. Give the function the value that you want to convert.
  Serial.print(imu.calcAccel(imu.ax), 2);
  Serial.print(", ");
  Serial.print(imu.calcAccel(imu.ay), 2);
  Serial.print(", ");
  Serial.print(imu.calcAccel(imu.az), 2);
  Serial.println(" g");

}

void printMag()
{
  // To read from the magnetometer, you must first call the
  // readMag() function. When this exits, it'll update the
  // mx, my, and mz variables with the most current data.
  imu.readMag();

  // Now we can use the mx, my, and mz variables as we please.
  // Either print them as raw ADC values, or calculated in Gauss.
  Serial.print("M: ");
  // If you want to print calculated values, you can use the
  // calcMag helper function to convert a raw ADC value to
  // Gauss. Give the function the value that you want to convert.
  Serial.print(imu.calcMag(ironCorrction(0, imu.mx)), 2);
  Serial.print(", ");
  Serial.print(imu.calcMag(ironCorrction(1, imu.my)), 2);
  Serial.print(", ");
  Serial.print(imu.calcMag(ironCorrction(2, imu.mz)), 2);
  Serial.println(" gauss");
}

// Calculate pitch, roll, and heading.
// Pitch/roll calculations take from this app note:
// http://cache.freescale.com/files/sensors/doc/app_note/AN3461.pdf?fpsp=1
// Heading calculations taken from this app note:
// http://www51.honeywell.com/aero/common/documents/myaerospacecatalog-documents/Defense_Brochures-documents/Magnetic__Literature_Application_notes-documents/AN203_Comp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
void printAttitude(
  float ax, float ay, float az, float mx, float my, float mz)
{
  float roll = atan2(ay, az);
  float pitch = atan2(-ax, sqrt(ay * ay + az * az));

  float heading;
  if (my == 0)
    heading = (mx < 0) ? 180.0 : 0;
  else
    heading = atan2(mx, my);

  //  heading -= DECLINATION * PI / 180;

  if (heading > PI) heading -= (2 * PI);
  else if (heading < -PI) heading += (2 * PI);

  // Convert everything from radians to degrees:
  heading *= 180.0 / PI;
  pitch *= 180.0 / PI;
  roll  *= 180.0 / PI;

  Serial.print("Pitch, Roll: ");
  Serial.print(pitch, 2);
  Serial.print(", ");
  Serial.println(roll, 2);
  Serial.print("Heading: "); Serial.println(heading, 2);
}

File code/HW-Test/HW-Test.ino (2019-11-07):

/*
 * External connections during the test: 
 *  - 14V external power (J4)
 *  - USB connected and terminal open
 *  - Jumper on J2 (after powerup)
 *  - short RX/TX on J9 (after powerup)
 *  - RS232 plug that shortens RX/TX (pin 2 and 3)
 *  - M1 - I1, I2:
 *    J4-M1A / J1-I1 <-> 20 Ohm <-> J4-M1B / J1-I2
 *    + J4-M1A connected with J1-I1
 *    + J4-M1B connected with J1-I2
 *    + J4-M1A connected to a 20Ohm resistor to J4-M1B
*  - M2 - I3:
 *    J3-M2A <-> 10 Ohm <-> J1-I3 <-> 10 Ohm <-> J3-MB 
 *    + J3-M2A connected with 10 Ohm resistor
 *    + J3-M2B connected with 10 Ohm resistor
 *    + J1-I3 is connected with both resistors
 *  - Relay K2 / ADS1115
 *    + J5-A0 <-> J5-GND
 *    + J5-A1 (+ Pulldown) <-> J3-NC
 *    + J5-5V <-> J3-COM
 *    + J5-A2 (+ Pulldown) <-> J3-NO
 *  - Ethernet connected to a network with a DHCP server
 * 
 * 
 *  Uses
 *    + arduino-can: https://github.com/sandeepmistry/arduino-CAN
 */

// IO pins --------------------------------
#define ANALOG_INPUT1 36
#define ANALOG_INPUT2 39
#define ANALOG_INPUT3 34
#define I2C_SDA 32
#define I2C_SCL 33
#define VNH_A_PWM 4
#define VNH_B_PWM 12
#define F9P_RX 13
#define F9P_TX 14
#define RS232_RX 16
#define RS232_TX 15
#define UART_RX 2
#define UART_TX 0
#define CAN_TX 5
#define CAN_RX 35
// Ethernet
#define ETH_CLK_MODE    ETH_CLOCK_GPIO17_OUT
#define ETH_POWER_PIN   -1
#define ETH_TYPE        ETH_PHY_LAN8720
#define ETH_ADDR        0
#define ETH_MDC_PIN     23
#define ETH_MDIO_PIN    18

// includes
#include "Adafruit_ADS1015.h"
#include <Wire.h>
#include "driver/gpio.h"
#include <LSM9DS1_Registers.h>
#include <SparkFunLSM9DS1.h>
#include <LSM9DS1_Types.h>
#include <ETH.h>
#include <CAN.h>

// global variables
int check = 1;
char byteRead;
char sentByte = 'U';
byte ethernetStatus = -1;
int gyros[3];
float magAbs[3];


// instances
LSM9DS1 imu;

void setup() {
  //Initialize serial and wait for port to open:
  Serial.begin(115200);
  Serial.println("-------------------------------------");
  Serial.println("ESP32 - F9P - IO-Board Tester");
  Serial.println("-------------------------------------");
  Serial.println("");
  // Setup IO

  // initialize PINs for VNHs
  pinMode(VNH_A_PWM, OUTPUT);
  pinMode(VNH_B_PWM, OUTPUT);

  // analog inputs - set input to explicit disable any pullups
  pinMode(ANALOG_INPUT1, INPUT);
  pinMode(ANALOG_INPUT2, INPUT);
  pinMode(ANALOG_INPUT3, INPUT);
  analogReadResolution(10); // Default of 12 is not very linear. Recommended to use 10 or 11 depending on needed resolution.
  analogSetAttenuation(ADC_11db); // Default is 11db which is very noisy. But needed for full scale range  Recommended to use 2.5 or 6.

  // Serial for F9P, RS232, Light
  gpio_pad_select_gpio(GPIO_NUM_13);
  gpio_set_direction(GPIO_NUM_13, GPIO_MODE_OUTPUT);
  
  gpio_pad_select_gpio(GPIO_NUM_15);
  gpio_pad_select_gpio(GPIO_NUM_16);
  gpio_set_direction(GPIO_NUM_15, GPIO_MODE_OUTPUT);
  gpio_set_direction(GPIO_NUM_16, GPIO_MODE_INPUT);
  
  gpio_pad_select_gpio(GPIO_NUM_2);
  gpio_set_direction(GPIO_NUM_2, GPIO_MODE_INPUT);
  gpio_pad_select_gpio(GPIO_NUM_0);
  gpio_set_direction(GPIO_NUM_0, GPIO_MODE_OUTPUT);
  
  // PINs for CAN
  pinMode(CAN_RX, INPUT);
  gpio_pad_select_gpio(GPIO_NUM_35);
  gpio_set_direction(GPIO_NUM_35, GPIO_MODE_INPUT);
  pinMode(CAN_TX, OUTPUT);

  

}

bool i2cTestAdress(byte address) {
  byte error;

    // The i2c_scanner uses the return value of
    // the Write.endTransmisstion to see if
    // a device did acknowledge to the address.
    Wire.beginTransmission(address);
    error = Wire.endTransmission();

    if (error == 0) {
      Serial.println("Found");
      return true;
    } else if (error == 4) {
      Serial.println("Unknown error");
      return false;
    } else{
      Serial.println("Not found");
      return false;
    }
  }


uint8_t getByteI2C(int address, int i2cregister) {
  Wire.beginTransmission(address);
  Wire.write(i2cregister);
  Wire.endTransmission(false);
  uint8_t state = Wire.requestFrom(address, 1, (int)true);
  return Wire.read();
}


uint8_t setByteI2C(int address, byte i2cregister, byte value) {
  Wire.beginTransmission(address);
  Wire.write(i2cregister);
  Wire.write(value);
  return Wire.endTransmission();
}

void loop() {
  switch (check) {
    // Start with everything that can be done before all (external) connections are connected
    case 1: {
      Serial.println("");
      Serial.println("configure CAN interface");
      // "init"
      // configure CAN-interface
      CAN.setPins(CAN_RX, CAN_TX);

      // start the CAN bus at 500 kbps
      if (!CAN.begin(500E3)) {
        Serial.println("Starting CAN failed!");
        check = 99;
        break;
      }
    } break;
    case 2:
      Serial.println("");
      // enable I2C interface
      Wire.begin(I2C_SDA, I2C_SCL, 400000);
      Serial.println("Checking I2C - Bus: ");
      Serial.print("  FXL6408 port extender (0x43): ");
      if (! i2cTestAdress(0x43)) {
        check = 99;
      }
      Serial.print("  ADS1115               (0x1C): ");
      if (! i2cTestAdress(0x48)) {
        check = 99;
      }
      Serial.print("  LSM9DS1 Magnetometer  (0x1C): ");
      if (! i2cTestAdress(0x1C)) {
        check = 99;
      }
      Serial.print("  LSM9DS1 Accelerometer (0x6A): ");
      if (! i2cTestAdress(0x6A)) {
        check = 99;
      }     
      break;
    case 3: {
        Serial.println("");
        Serial.println("Configure the FXL6408");
        // direction (Input/Output)
        setByteI2C(0x43, 0x03, 0b11111110);
        // disable High-Z on outputs
        setByteI2C(0x43, 0x07, 0b00000001);
        // en-/disable Pullup/downs
        setByteI2C(0x43, 0x0B, 0b00000001);
        // set direction of the pull
        setByteI2C(0x43, 0x0D, 0b00000001);
      } break;
    case 4: {
        Serial.println("");
        Serial.print("Konfigure the LSM9DS1: ");
        imu.settings.device.commInterface = IMU_MODE_I2C;
        imu.settings.device.mAddress = 0x1C;
        imu.settings.device.agAddress = 0x6A;
        imu.settings.mag.scale = 4; // Set mag scale to +/-12 Gs
        imu.settings.mag.XYPerformance = 3; // Ultra-high perform.
        imu.settings.mag.ZPerformance = 3; // Ultra-high perform.
        imu.settings.mag.lowPowerEnable = false;
        if (!imu.begin()) {
          Serial.println("Failed");
          check = 99;
        } else {
          Serial.println("Ok");
        }
      } break;
    case 5: {
        Serial.println("");
        Serial.println("Configure Ethernet (LAN8720)");

        // "init"
        // enable the LAN8720
        setByteI2C(0x43, 0x05, 0b00000010);
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

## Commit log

2019-03-17 first revision
    [ADS-Input.sch, Parts.ods, ProtectedInput.sch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]
2019-04-23 first version of the new feature set
    [ADS-Input.sch, Parts.ods, ProtectedInput.sch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]
2019-04-23 missing files added
    [F9P-IO.sch, I2C-Signal.sch, IMU.sch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]
2019-04-24 Added labels, added coper on the back to balance (avoid bending)
    [mainPCB-B.Cu.gbl, mainPCB-B.Mask.gbs, mainPCB-B.SilkS.gbo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]
2019-04-24 fixed two vias (+5V instead of GND)
    [mainPCB-B.Cu.gbl, mainPCB-B.Mask.gbs, mainPCB-B.SilkS.gbo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]
2019-04-25 Updated drill files with gerber - some missmatch had happend
    [mainPCB-B.Cu.gbl, mainPCB-B.Mask.gbs, mainPCB-B.SilkS.gbo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]
2019-04-25 Changed some values - RC for the inputs to lower frequencys, reduced lines on the BOM by some minor value changes
    [ADS-Input.sch, I2C-Signal.sch, Parts.ods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]
2019-04-25 Addes schematics as pdf
2019-04-25 Started adding partnumbers from digikey
    [Parts.ods]
2019-04-30 Small optimization for soldermask
    [mainPCB-B.Cu.gbl, mainPCB-B.Mask.gbs, mainPCB-B.SilkS.gbo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]
2019-05-02 A few more vias for the main 12V input (top layer -> third layer)
    [mainPCB-B.Cu.gbl, mainPCB-B.Mask.gbs, mainPCB-B.SilkS.gbo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]
2019-05-12 changed soring of parts
    [Parts.ods]
2019-05-18 Changed Hardware-Test for the new board, not final
2019-05-18 added gyro calibration
2019-05-19 simplyfied gyro calibration
2019-05-19 fixes for small Load-Test
    [Load-Test.ino]
2019-05-20 changed connection of the LAN8720A, RST to the FXL6408 and MDIO to the ESP32 (where RST was before). fixes #2
    [LAN8720.sch, mainPCB.kicad_pcb, mainPCB.sch]
2019-05-20 changed some soldering pads to termal relief where no high current is expected. fixes #3
    [mainPCB.kicad_pcb]
2019-05-20 removed the relais-error led
    [mainPCB.kicad_pcb, powerSupply.sch]
2019-05-20 fixed number of parts in the parts-List
    [Parts.ods]
2019-05-20 Moved the LSM9DS1 under F9P board, fixes #6
    [mainPCB.kicad_pcb]
2019-05-20 Moved the USB and RS232 connectors a bit, more distance, so easier to use both at the same time
    [mainPCB.kicad_pcb]
2019-05-20 Reduced the number of vias
    [mainPCB.kicad_pcb]
2019-05-20 Removed 'internal soldering bridges' for easier inspection
    [mainPCB.kicad_pcb]
2019-05-20 Minor cosmetic changes on tracks
    [mainPCB.kicad_pcb]
2019-05-20 Moved Setup button switch. fixes #7
    [mainPCB.kicad_pcb]
2019-05-22 Added five fiducials. fixes #3
    [mainPCB.kicad_pcb]
2019-05-22 Moved mounting hole. fixes #1
    [mainPCB.kicad_pcb]
2019-05-22 Minor cleanups
    [mainPCB.kicad_pcb]
2019-05-23 Simplified some tracks
    [mainPCB.kicad_pcb]
2019-05-23 Minor cosmetic changes, Added fiducials. fixes #4
    [mainPCB.kicad_pcb]
2019-05-23 Changed Version on the Board
    [mainPCB.kicad_pcb]
2019-05-23 Updated footprints of the SMT connectors, fixes #8. In addition simplified some tracks.
    [mainPCB.kicad_pcb]
2019-05-23 Generated new gerber files. Fixes #9
    [mainPCB-B.Cu.gbl, mainPCB-B.Mask.gbs, mainPCB-B.SilkS.gbo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]
2019-05-23 kicad updated some internal timestamps
    [mainPCB.kicad_pcb]
2019-05-23 fixed 3d-references
    [mainPCB.kicad_pcb]
2019-05-23 add rendering, add schematics as pdf
2019-05-23 Updated BOM/Part-List. Fixes #11
    [Parts.ods]
2019-05-25 Changed a bit the parameters for solderstop (increased min width to 0.15mm) and reduced a bit the padsize for the solderpaste-stecil (-2.5%)
    [mainPCB.kicad_pcb]
2019-05-25 Updated gerber files
    [mainPCB-B.Cu.gbl, mainPCB-B.Mask.gbs, mainPCB-B.SilkS.gbo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]
2019-05-30 Added an other uart for ardusimple RTK2Bligh daughterboard on top of the normal RTK2B. Removed two LEDs to free up PINs
    [ProtectedInput.sch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]
2019-06-01 Minor cosmetic changes (moved some labels)
    [mainPCB.kicad_pcb]
2019-06-03 Added fiducials (fixes #4), updated BOM, updated gerber files.
    [Parts.ods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]
2019-07-11 a mostly self contained self test for the PCB, online some wireing in the plugs neccessary
2019-07-16 fixed copy and paste error in the parts.ods. Fixes #16
    [Parts.ods]
2019-07-21 make pickplacePDF, order CSV for 'www.seeedstudio.com'PCBA
    some files to order 'www.seeedstudio.com' PCB & PCB Assembly.
    Manufacturer Part Number(MPN) ,and DataSheet link list
    [AllPartslist.csv, SeeedOrder.csv, SelfSolderingParts.csv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]
2019-07-23 Update README.md
    Explained the shared pin layout of the rtk2blight uart (J2)
2019-07-24 Added code to test the CAN-bus interface with two PCBs (one DUT, one as CAN-Responder)
2019-07-24 Updated outdated rendering of the PCB
2019-08-05 Fixed #3 thermal relief pads. Removed an unwanted bridge between the ground planes
    [mainPCB-B.Cu.gbl, mainPCB-B.Mask.gbs, mainPCB-B.SilkS.gbo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]
2019-08-06 Pull FORCEON to high on RS232 to avoid standby, fixed #18. Also implemented virtual symbol for permanent fiducials
    [RS232.sch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]
2019-08-25 Removed inductor in front of ADS1115, replaced with resistor (RC should be enough, comparison with the RC on the LSM9DS1 did not show many differences)
    [ADS-Input.sch, Parts.ods, mainPCB.kicad_pcb]
2019-08-25 Edited some footprints (connectors, fxl6408). Fixes #19
    [mainPCB.kicad_pcb]
2019-08-25 Changed a capacitor in the power supply (10u to 22u) for more capacity/stability
    [Parts.ods, powerSupply.sch]
2019-08-25 Turned some Labels for the User, so he can read them with the ESP on top
    [mainPCB.kicad_pcb]
2019-08-25 Update of gerber files, ibom, rendering, printed schematics, files for seedstudio
    [AllPartslist.csv, Parts.ods, SeeedOrder.csv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]
2019-08-26 Added a alternative Part number
    [Parts.ods]
2019-08-26 Added a better capacitor
    [Parts.ods]
2019-09-07 Removed center to avoid drilling at some manufactures
    [mainPCB.kicad_pcb]
2019-09-07 Updated gerber
    [mainPCB-B.Cu.gbl, mainPCB-B.Mask.gbs, mainPCB-B.SilkS.gbo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]
2019-10-06 First try of a case
    [Case_Baseplate.scad, Case_Baseplate.stl, Case_MainCover.scad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]
2019-10-10 Fixed different mistakes
    [Case_Baseplate.scad, Case_Baseplate.stl, Case_MainCover.scad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]
2019-11-07 Changed the HW-Test. Less manual intervention, no external network connection required (only a second known good pcb), test the IMU
2019-11-07 Mechanical parts for the Test Setup
    [Base.scad, Base.stl, Middle.scad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]
2019-11-07 Minor Adjustments for the USB/RS232 openings
    [Case_MainCover.scad, Case_MainCover.stl]
2019-11-07 Rename Case
    [Case_Baseplate.scad, Case_Baseplate.stl, Case_MainCover.scad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]
2019-11-07 Switched to 3mm screws, fixes #30
    [Case_Baseplate.scad, Case_Baseplate.stl, Case_MainCover.scad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]
2019-11-07 two small holder and a bit more space for cable management, fixes #32 and fixes #31
    [Case_Baseplate.scad, Case_Baseplate.stl]
2019-11-10 Added a 45° angle to the outside corner, moved the USB/RS232 cut a bit for better fitting the pcb
    [Case_Baseplate.scad, Case_Baseplate.stl, Case_MainCover.scad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]
2019-11-10 Added a small support for the top
    [Case_MainCover.scad, Case_MainCover.stl]
2019-11-11 Made the thinner/transparent parts a little bit thinner
    [Case_MainCover.scad, Case_MainCover.stl]
